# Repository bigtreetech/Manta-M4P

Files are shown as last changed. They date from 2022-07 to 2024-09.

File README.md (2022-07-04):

# [切换到中文版](./README_zh_cn.md)

# Note
## Here’s BIGTREETECH! For Makers, by makers!
* We appreciate all of your support to BIGTREETECH! To offer an excellent experience of creation to every makers,We’re devoted to design and produce high-quality and durable accessories!

## How to contact:
### If you have any technical issue,please don’t hesitate contact us:
* BIGTREETECH: service004@biqu3d.com

### Follow us on social media to get more news:
* Facebook: https://www.facebook.com/BIGTREETECH/
* Twitter: https://twitter.com/BigTreeTech
* Instagram: https://www.instagram.com/bigtreetech_official/
* Official Site: https://bigtree-tech.com/

## Purchase link:
* M4P/M8P/CB1: https://www.biqu.equipment/collections/control-board/products/manta-m4p-m8p

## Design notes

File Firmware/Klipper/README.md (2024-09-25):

# [切换到中文版](./README_zh_cn.md)

# How to use Klipper on Manta M4P

## NOTE: 

- This motherboard comes with a bootloader that allows firmware updates via the MCU SD card.

## Build Firmware Image

1. **Precompiled firmware** (The source code version used is [Commits on Jul 1, 2022](https://github.com/Klipper3d/klipper/commit/1636a9759bc2d5f162312ac8bf5823e95e0ad053))
   - [firmware-USB.bin](./firmware-USB.bin) - Use USB to communicate with SoC. The USB of MCU on M4P has been connected with CB1/CM4 on the board. After updating the firmware, it can be used without additional wiring.

2. **Build your own firmware**
   1. Refer to [Klipper's official installation](https://www.klipper3d.org/Installation.html) to download Klipper source code to the Raspberry Pi.
   2. Build the micro-controller with the configuration shown below. If your Klipper cannot select the following configuration, please update your Klipper source code.
      - [*] Enable extra low-level configuration options
      - Micro-controller Architecture = `STMicroelectronics STM32`
      - Processor model = `STM32G0B1`
      - Bootloader offset = `8KiB bootloader`
      - Clock Reference = `8 MHz crystal`
      - Communication interface = `USB (on PA11/PA12)`

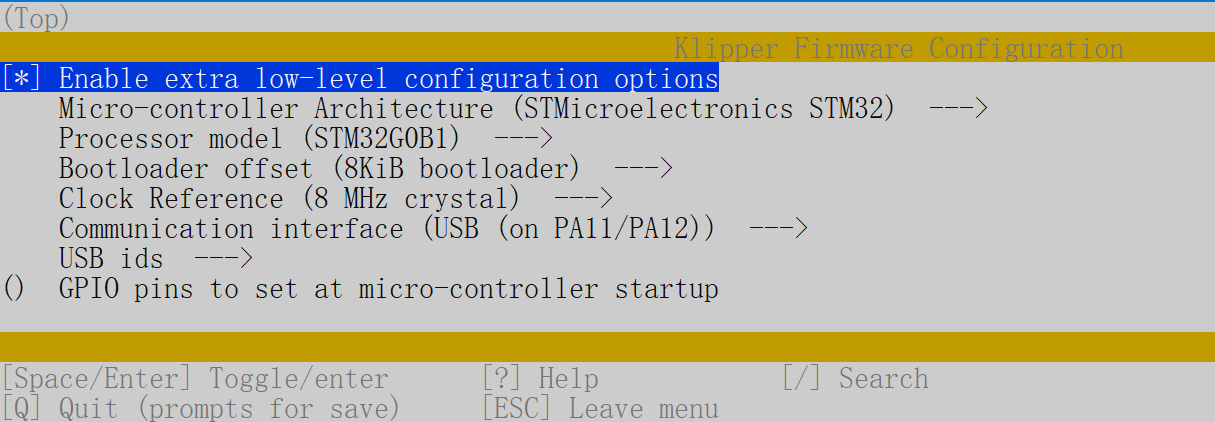
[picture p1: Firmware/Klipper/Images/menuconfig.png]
Configuration Screenshot
      

   3. Once the configuration is selected, press `q` to exit, and "Yes" when asked to save the configuration.
   4. Run the command `make`.
   5. The `klipper.bin` file will be generated in the folder `home/pi/klipper/out` when the `make` command is completed. You can use a Windows computer on the same LAN as the Raspberry Pi to copy `klipper.bin` from the Raspberry Pi to the computer with the `pscp` command in the CMD terminal, such as `pscp -C pi@192.168.0.101:/home/pi/klipper/out/klipper.bin c:\klipper.bin`. The terminal may prompt that the server's host key is not cached and ask "Store key in cache? (y/n)." Please type `y` to store. It will then ask for a password; please type the default password `raspberry` for the Raspberry Pi.

## Firmware Installation

1. You can use the method in [Build Firmware Image 2.5](#build-firmware-image) or use a tool such as `Cyberduck` or `WinSCP` to copy the `klipper.bin` file from your Pi to your computer.
2. Rename the `firmware-USB.bin` or `klipper.bin` (in the folder `home/pi/klipper/out` built by yourself) to `firmware.bin`.
**Important:** If the file is not renamed, the bootloader will not be updated properly.
3. Copy the `firmware.bin` to the root directory of the MCU SD card (make sure the SD card is in FAT32 format).
4. Power off the motherboard.
5. Insert the MCU SD card.
6. Power on the motherboard.
7. After a few seconds, the motherboard should be flashed.
8. You can confirm that the flash was successful by running `ls /dev/serial/by-id`. If the flash was successful, this should now show a Klipper device, similar to:

   Device Screenshot
   
## Configure Printer Parameters
### Basic Configuration

1. See [Klipper's official installation](https://www.klipper3d.org/Installation.html) for "Configuring OctoPrint to use Klipper."
2. See [Klipper's official installation](https://www.klipper3d.org/Installation.html) for "Configuring Klipper." And use the configuration file [generic-bigtreetech-manta-m4p.cfg](./generic-bigtreetech-manta-m4p.cfg) as the underlying `printer.cfg`, which contains all the correct pinout for Octopus.
3. Refer to [Klipper's official Config_Reference](https://www.klipper3d.org/Config_Reference.html) to configure the features you want.
4. If you are using USB to communicate with the Raspberry Pi, run `ls /dev/serial/by-id/*` on the Raspberry Pi to get the correct motherboard ID number and set the correct ID number in `printer.cfg`.
    ```
    [mcu]
    serial: /dev/serial/by-id/usb-Klipper_stm32g0b1xx_190028000D50415833323520-if00
    ```

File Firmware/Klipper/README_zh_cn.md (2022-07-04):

# [View English version](./README.md)

# 在 Manta M4P 主板上使用 Klipper

## 注意: 

* 此主板出厂时自带了引导程序，允许通过 MCU SD 卡更新固件(firmware.bin)。

## 编译固件
1. 预编译的固件(预编译的固件源码版本是 [Commits on Jul 1, 2022](https://github.com/Klipper3d/klipper/commit/1636a9759bc2d5f162312ac8bf5823e95e0ad053))
   * [firmware-USB.bin](./firmware-USB.bin) 使用 USB 与树莓派通信。M4P 上的 MCU 的 USB 在板上与 CB1/CM4 已经连接好了，更新完固件即可使用，不需要额外的接线。

2. 自行编译最新版本的固件<br/>
   1. 参考 [klipper官方的安装说明](https://www.klipper3d.org/Installation.html) 下载klipper源码到树莓派
   2. 使用下面的配置去编译固件 (如果您的klipper无法选择如下的配置，请更新您的klipper源码)
      * [*] Enable extra low-level configuration options
      * Micro-controller Architecture = `STMicroelectronics STM32`
      * Processor model = `STM32G0B1`
      * Bootloader offset = `8KiB bootloader`
      * Clock Reference = `8 MHz crystal`
      * Communication interface = `USB (on PA11/PA12)`

      <br/>
   3. 配置选择完成后, 输入 `q` 退出配置界面，当询问是否保存配置是选择 "Yes" .
   4. 输入 `make` 命令开始编译固件
   5. 当 `make` 命令执行完成后，会在树莓派的`home/pi/kliiper/out`的文件夹中生成我们所需要的`klipper.bin`固件。你可以在CMD命令行终端中通过`pscp`命令把`klipper.bin`固件复制到与树莓派在同一个局域网下的电脑上。例如 `pscp -C pi@192.168.0.101:/home/pi/klipper/out/klipper.bin c:\klipper.bin`(命令行会提示 `The server's host key is not cached` 并且询问 `Store key in cache?((y/n)`, 输入 `y` 保存 host key，然后输入树莓派默认的密码：`raspberry`)

## 更新固件
1. 你可以使用 [编译固件 2.5](#编译固件) 中的方法或者使用 `cyberduck`、 `winscp` 工具软件从树莓派中将 `klipper.bin` 文件复制到电脑上
2. 将我们提供的`firmware-USB.bin`, 或者你自行编译的 `klipper.bin` 文件重命名为 `firmware.bin`<br/>
**提示:** 如果没有重命名为 `firmware.bin`，引导程序将不会识别并更新此文件
3. 复制 `firmware.bin` 到MCU SD卡的根目录中(确保SD卡的文件系统是FAT32格式)
4. 将主板断电
5. 插入MCU SD卡
6. 给主板通电
7. 仅需几秒钟，主板就会自动完成更新固件的步骤
8. 你可以输入 `ls /dev/serial/by-id` 查询主板的串口ID来确认固件是否烧录成功，如果烧录成功了会返回一个klipper的设备ID，如下图所示:

   <br/>

   (注意: 此步骤仅适用于USB通信的工作方式，如果使用USART通信则没有这种ID)

## 配置打印机的参数
### 基础配置
1. 参考 [klipper官方的安装说明](https://www.klipper3d.org/Installation.html) to `Configuring OctoPrint to use Klipper`
2. 参考 [klipper官方的安装说明](https://www.klipper3d.org/Installation.html) to `Configuring Klipper`. 并且使用我们提供的配置文件 [generic-bigtreetech-manta-m4p.cfg](./generic-bigtreetech-manta-m4p.cfg) 为基础去修改 `printer.cfg`, 此文件中包含了主板几乎所有的pinout
3. 参考 [klipper官方的配置说明Config_Reference](https://www.klipper3d.org/Config_Reference.html) 去配置你想要的特性和功能
4. 如果你想通过USB与树莓派通信，运行 `ls /dev/serial/by-id/*` 命令去查询主板的设备ID号，在 `printer.cfg` 设置查询到的实际设备ID号
    ```
    [mcu]
    serial: /dev/serial/by-id/usb-Klipper_stm32g0b1xx_190028000D50415833323520-if00
    ```

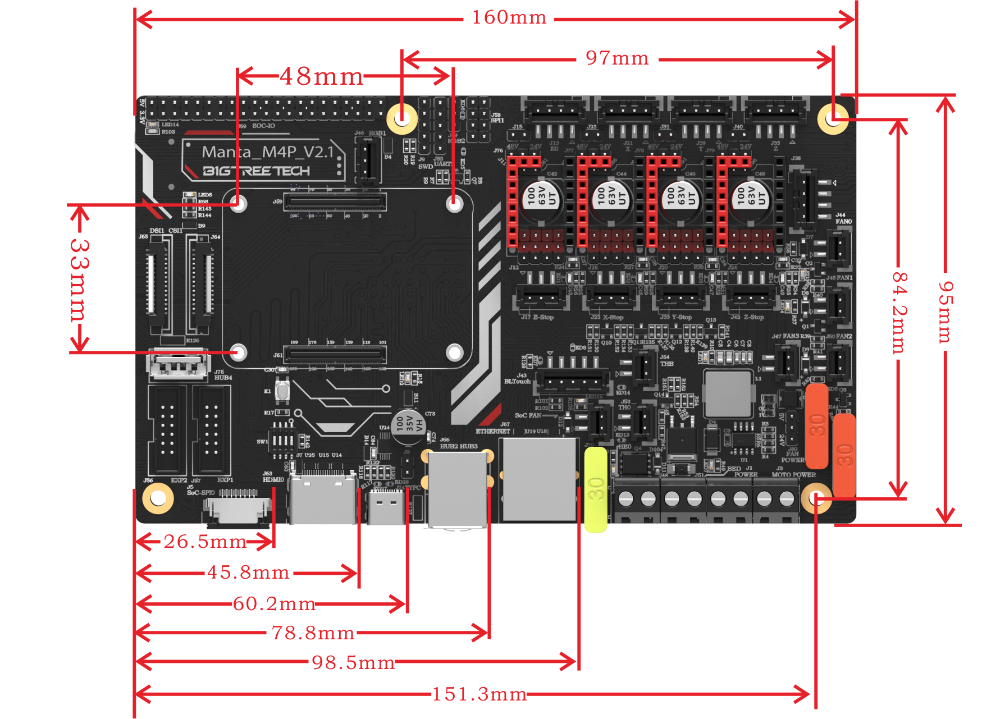
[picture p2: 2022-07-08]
Hardware/BIGTREETECH_Manta_M4P_V2.1_220608 SIZE.png

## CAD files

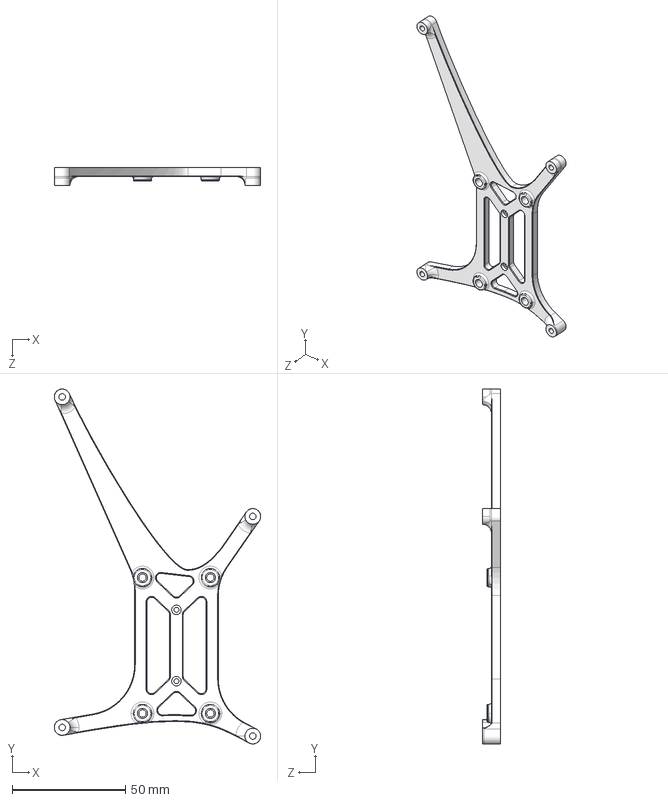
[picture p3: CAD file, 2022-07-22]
3D/M4P_Voron0_Mounting bracket.STEP
91.2 x 156.8 x 8.00 mm

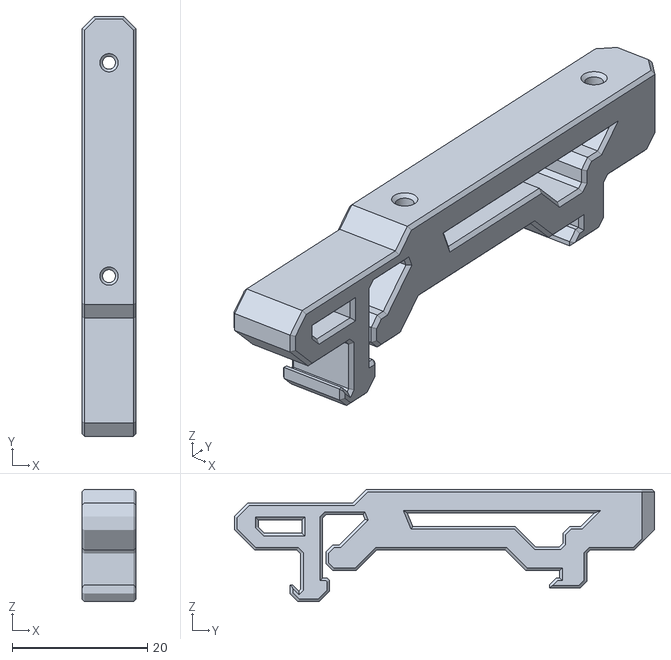
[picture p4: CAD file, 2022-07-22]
3D/DIN Clips.STL
8.00 x 62.0 x 16.6

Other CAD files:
3D/M4P_Voron0_Mounting bracket.STL

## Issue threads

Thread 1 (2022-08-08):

CB1 missing pins on IO

stas2z, 2022-08-08:
Seems like actual pinout of 40pin connector for CB1 rev 2.1 is wrong, ive checked all pins available for CB1 with libgpiod (gpioset) and found PG6/PG7/PG8/PG9, also as PC12/PC13 are not changing state. Other pins found in manual are ok.

Please provide actual CB1 to 40pin connector pinout.

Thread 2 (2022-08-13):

STM32G0B0 is missing from Klipper configuration

ebraiman, 2022-08-13:
When manually configuring marlin with Make menuconfig in klipper, there is not option for STM32G0B0 chipset.

Guilouz, 2022-08-14:
You must use STM32G0B1

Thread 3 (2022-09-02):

Manta-M4P with CB1 and BTT HDMI5

Kudach, 2022-09-02:
I have a problem with the activation of the BTT HDMI5 in the Manta-M4P and the CB1.

How do I activate the HDMI port so that I can use the manta board completely?

billru05, 2022-11-16:
Once you load the OS on the CB1 the HDMI should work, that's providing you did not install the dt-blob-disp1-cam1.bin, if you did not load the dt-blob-disp1-cam1.bin and your HDMI is not working you may need to look at your config.sys file in the boot dir

Tbone5114, 2022-12-29:
Did you find a solution?

billru05, 2022-12-29:
> Did you find a solution?
Solution to what or is this reply for ([Kudach](https://github.com/Kudach))

Tbone5114, 2022-12-29:
This was for @Kudach. I'm running into the same issue where my HDMI isn't working.

Mig1880, 2023-10-06:
I found I had to power the hdmi5 via a USB C with hdmi connected. My issue is now I'm only getting 2/3rd of a screen
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

javcab2003, 2024-02-17:
> I have a problem with the activation of the BTT HDMI5 in the Manta-M4P and the CB1.
>
> How do I activate the HDMI port so that I can use the manta board completely?

Hi, did you find the solution?

I have the same issue, I have the CBI and the EZE3 but I cannot see anything in the display, in the web interface I can see the USB recognised for the HDMI connection but the display "HDMI 5" shows nothing. I tried to reinstall the Klipper screen and checked the log files but there is nothing that is in error status or similar
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

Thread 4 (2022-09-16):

M4P / M8P CAN support with EBB42

cstrachan88, 2022-09-16:
I would like to use the M4P (with a Raspberry Pi CM4) and the EBB42 tool board. Is this combination possible? I will be running Klipper on the raspberry pi which supports CAN, but there are no shown outputs to connect to the EBB42 board. Would using the U2C as an intermediary suffice?

If not, are there any plans for future M4P style boards with CAN capabilities? If the M4P had the EZ style motor controllers, CAN-FD, and an CM4 socket, it would be perfect.

TURNERO, 2022-10-19:
I've not tried yet, since my board hasn't arrived but I'm planning on using one of the UART ports on the board to drive an SN65HVD230 canbus tranceiver. These instructions are confirmed to work for other MCUs, not just the PICO: https://github.com/rootiest/zippy-klipper_config/blob/master/guides/Guide-pico_can.md.

I'll let you know at the weekend if it works. If my board doesn't arrive soon, I'll try it with my SKR 1.3.

tnap1979, 2022-10-25:
You can use the u2c with ebb42 just fine, as the u2c acts as a USB mcu with can support

dury10, 2023-07-01:
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

did you manage to make it run on can?

Coolbobjoe, 2023-12-18:
> You can use the u2c with ebb42 just fine, as the u2c acts as a USB mcu with can support

Have you figured out how to do this? I cannot for the life of me get a usable uuid off the device and have semi-confirmed I dont have a bad chip by flashing within STM32.

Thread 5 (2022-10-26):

RGB ports configuration

acosano, 2022-10-26:
Hi.  Ispend q few days now trying to get the RG porst to work with no sucess. I try diferent  RGBW and still no go. I'musing klipper and the code is I'm using works on any other printer wbut not on the MP4. Any advice what I'm doing wrong.
[neopixel logo_rgb]
pin: PD0 or PD1 no sucess
chain_count: 24
color_order: GRB
initial_RED: 0.0
initial_GREEN: 0.0
initial_BLUE: 0.0

fastslash25, 2022-11-23:
Hey, I was able to use the PD1 RGB port on my m4p.
I use this in my printer.cfg:

[neopixel my_led]
pin: PD1
chain_count: 23

And I use:
https://github.com/digitalninja-ro/klipper-neopixel/blob/1ec86884bd5b384e4b6a35c39c5a0f6598d76189/led_progress.cfg

acosano, 2022-11-23:
I use the same cfg and it works fine on the Octopus Pro but for some reason  Ican't get it to work on the MP4. Wil lgive it tomorrow another try.

Aizel330, 2022-12-22:
hey, any luck on this? I'm having the same problem and I really can't figure out what I'm doing wrong...

lyonmaster, 2023-01-16:
Any resolve on this issue, i cant get mine to work either.

emersonsc, 2023-02-07:
Same issue. Neither of my RGB ports function

Aizel330, 2023-02-20:
Hey guys I've solved my problem by connecting an addictional vcc and gnd to my leds, apparently the board alone it's not able to drive many leds so it's better if you get your 5/12v elsewhere and just control the leds via the control pin

Coolbobjoe, 2023-12-18:
> Hey guys I've solved my problem by connecting an addictional vcc and gnd to my leds, apparently the board alone it's not able to drive many leds so it's better if you get your 5/12v elsewhere and just control the leds via the control pin

Not sure if this will help anyone down the road, if you are having issues with flickering/ random colors/ neopixels not activating at all, and you are using a separate power source. Try linking the ground of your separate power source not just to the neopixels themselves, but to the ground port on the rgb port itself, in addition. This helps with a floating ground issue that can cause headaches with longer chain lengths!

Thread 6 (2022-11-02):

Adxl345 wiring

Freddyb888, 2022-11-02:
How do I wire a adxl345 on the Manta-M4P with cb1?

Aizel330, 2022-11-07:
Hi dear, I managed to wired and use an adxl345 using the spi port on the m4p, I'll attach some images, hopefully they are clear enough
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

then basically it's just matter of connecting these pins together and add this to your printer.cfg

[adxl345]
cs_pin: PD9
spi_bus: spi1
axes_map: y,x,z

the axes_map need to be modified depending on the orientation of your particular adxl345 so some testing may be needed to correct the orientation and make sure that the compensation is on the right axes. if anyone needs more infos I'll be more than happy to help.

Freddyb888, 2022-11-11:
Thanks, but is not possible to connect to the 40 gpio pins that are present on the btt manta m4p with cb1? Thanks again

Aizel330, 2022-11-11:
https://github.com/bigtreetech/CB1/issues/14#issuecomment-1264667543 I think that could help you with that, hopefully.

Freddyb888, 2022-11-11:
Thanks a lot. I think it will work.

Aizel330, 2022-11-12:
no problem, enjoy!

ox006, 2023-03-16:
how can i connect mpu6050 with M8p/cb1

Closed 2022-11-11.

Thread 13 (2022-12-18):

Alias x_step_pin mapped to PC6 - can't alias to PB3

iMattmax, 2022-12-18:
I flashed my Manta M4P with klipper and lashed the MCU with the CM4-Modul. Now, I get this error "Alias x_step_pin mapped to PC6 - can't alias to PB3" and I don't lnow how to fix this. Can someone help?

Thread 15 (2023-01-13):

Manta-M4P with CB1 and BTT SoC-Fan

DiTheRX, 2023-01-13:
When setting up the SoC-Fan, no voltage is applied to the port

ilai82, 2023-01-15:
How to properly connect the fan to this connectors?

Freddyb888, 2023-02-02:
Would like to know this too

Pneumanifest, 2023-02-03:
You have it defined as the PC15 which is the E0-DET
That fan is connected to the cb1 GPIO. I'm not sure is you need to set up the cb1 as a host MCU or not but the pin is defined as such.

    pin: host: gpio79

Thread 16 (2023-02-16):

M4P green led stopped lighting up(led2) and board has stopped working

the-m0m0, 2023-02-16:
I had the Manta m4p working just fine, then randomly, while I unplugged the HDMI manta board stopped working. It still provides power to all components plugged into it but no longer responds or starts. When provided power, the only light to show up is red(led 1).  What is wrong with it? are there any possible fixes? I've already attempted to completely restart and reinstall but once I plug it in with HDMI big tree's logo won't come up and won't connect to wifi.

the-m0m0, 2023-02-17:
I have replaced my cb1 one and that seems to have fixed the problem

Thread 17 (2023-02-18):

Filament runout port

kieraneglin, 2023-02-18:
The manual says there's a filament runout port, but the board diagram doesn't include a SFS or FIL-DET like the M8P does.

Is there a dedicated filament runout port?

Pneumanifest, 2023-02-18:
E0-STOP is the filament runout port

Closed 2023-02-21.

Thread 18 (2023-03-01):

HDMI does not work on V2.1 but does work on V2.2

kieraneglin, 2023-03-01:
I have an HDMI screen that does work on a V2.2 board but does not work on a V2.1. What do I need to do on the V2.1 board to get HDMI working?

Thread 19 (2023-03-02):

Can you connect a filament runout sensor to this board?

kozross, 2023-03-02:
The manual claims it's possible, but I can't find any connection on the board named `FIL-DET`, or indeed, any `-DET`-type at all. Am I missing something?

Pneumanifest, 2023-03-02:
FIL-DET == E0_STOP

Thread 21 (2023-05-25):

No bootloader Manta M4P-CB1 issue during set up

Park8706, 2023-05-25:
Hello, I am having an issue where I am reaching the stage where I am setting up the firmware for klipper. I am using a terminal and get to the makemenu command. It pulls up the settings which all match that shown in the install documentation except for the boot load offset. Instead of the desired setting it is saying "no bootloader". I am not sure what I might be missing or have done wrong. Any help would be appreciated.

Pneumanifest, 2023-05-26:
Down to highlight that option, then use the space or right arrow to go into it. Then select the option in there and again space or right arrow to select. Left arrow to go back to previous menu page.

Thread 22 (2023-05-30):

ls /dev/serial/by-id/ always returns no file or directory found.

Park8706, 2023-05-30:
I have used both a compiled flash and one downloaded on the github along side the OS and in both cases I get the same error with my USB plugged into my PC or 3d Printer.

yzheka, 2023-06-17:
What does `dmesg` command says? I had similar problem and it appeared that USB was shut down due to EMI produced by my PSU.

Park8706, 2023-06-19:
> What does `dmesg` command says? I had similar problem and it appeared that USB was shut down due to EMI produced by my PSU.

I currently don't have the board as our dev has it atm. The issue for me ended up being I needed to flash the board without the CB1 board plugged into the manta for it to properly take the firmware. After that it worked fine and the serial pulled up.

Coolbobjoe, 2023-12-18:
I have no idea why this worked for me but...
try ls /dev/serial/by-path/

This was the only way I could find a path, not sure exactly where I found this, I had been struggling for over 2 days to get a usable pathway but this for some reason worked!

yzheka, 2023-12-18:
I have noticed that if i installed a 32 bit OS image it appears normal

Pneumanifest, 2023-12-20:
> reason

This is likely due to using a distro that has the known bug that causes this exact issue.
You can find more information about that here https://klipper.discourse.group/t/debian-bullseye-bug-causing-klipper-to-no-longer-find-the-printer-board/8231

warpwookie, 2024-03-17:
@yzheka where is the 32bit image file can you provide a link?

yzheka, 2024-03-17:
> @yzheka where is the 32bit image file can you provide a link?

I used raspberry pi imager app

warpwookie, 2024-03-20:
> > @yzheka where is the 32bit image file can you provide a link?
>
> I used raspberry pi imager app

Are you using CB1 or CM4?

yzheka, 2024-03-21:
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

That is strange, now i have no issue with both cm4 and cb1 using latest os image. Both are working fine.

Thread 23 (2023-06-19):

M4P_Voron0_Mounting bracket. STL does not fit the mounting holes to the board

AleksKar-Bon, 2023-06-19:
3 D model M4P_Voron0_Mounting bracket does not fit the mounting holes to the board

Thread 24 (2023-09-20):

How to connect SFS 2.0?

asychev, 2023-09-20:
One cable from SFS 2.0 goes to E0-STOP, this is clear.
Where to connect second?

Pneumanifest, 2023-09-22:
To another available endstop. Like E1-stop. It really depends on your board and setup.

asychev, 2023-09-22:
> To another available endstop. Like E1-stop. It really depends on your board and setup.

What other endstops besides not available XYZ can be used?

Pneumanifest, 2023-09-22:
> > To another available endstop. Like E1-stop. It really depends on your board and setup.
>
> What other endstops besides not available XYZ can be used? I hope it was clear the question is about M4P because, well, this is M4P repository, isn't it?..

Like E1-STOP, it depends on what board you have to what is available.

asychev, 2023-09-23:
> Like E1-STOP, it depends on what board you have to what is available.

It is some joke or what? We are in M4P repository, so it means we talk about (surprise!) M4P. And it does not have other usable endstops like E1-STOP.

Pneumanifest, 2023-09-23:
> > Like E1-STOP, it depends on what board you have to what is available.
>
> It is some joke or what? We are in M4P repository, so it means we talk about (surprise!) M4P. And it does not have other usable endstops like E1-STOP.

My sincere apologies. I was in another repo and talking with several others I did notice the repo and assumed it was for the SFS2. For the M4P you might be able to use the probe pin but you would have to make a connector to fit. I actually use it on the M4P now, but I Also have a microprobe so my z-stop was free to use.

Coolbobjoe, 2023-12-18:
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

Can you share how your cfg settings for this? I have the exact same setup and need to get that figured out once I finally get canbus over U2C working finally. Was a bit confused on how to accomplish this.

Pneumanifest, 2023-12-18:
I use the z-stop and e-stop

`[filament_switch_sensor switch_sensor]
switch_pin: PC15 #E0-stop
pause_on_runout: False
runout_gcode:
  PAUSE # [pause_resume] is required in printer.cfg
  M117 Filament loss detected

[filament_motion_sensor encoder_sensor]
switch_pin: PC2 #Z-stop
detection_length: 2.88
extruder: extruder
pause_on_runout: False
runout_gcode:
  PAUSE # [pause_resume] is required in printer.cfg
  M117 No motion detected`

Coolbobjoe, 2024-01-02:
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

Did you have to repin the connectors or anything? I am only getting a solid red light out of mine.

Pneumanifest, 2024-01-03:
No repining needed. The red and blue is in the first driver endstop and the black and green are in the last.
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

Str8Gamin420, 2024-01-19:
hi, i too am only getting a solid red light!

Hilacha2, 2025-03-05:
hola, lograron hacer funcionar el sensor de filamento?

Jecks85, 2025-05-13:
> No repining needed. The red and blue is in the first driver endstop and the black and green are in the last. 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

Thank you 😊

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

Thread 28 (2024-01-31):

Unable to read tmc uart 'stepper_z' register IFCNT

greggs12, 2024-01-31:
when I try to home any axis or all of them I get this error.

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

[klippy (5).log](https://github.com/bigtreetech/Manta-M4P/files/14116661/klippy.5.log)

warpwookie, 2024-03-21:
Make sure you are using the tmc2240 profile, and not the tmc2209 on from the klipper config file in the EBB github repo,

hitman01560, 2025-04-02:
getting the same errors since I put jumpers for sensorless homing on X & Y like in the manual. should I put jumpers on UART pins too to get sensorless homing? how did you resolve this problem please?

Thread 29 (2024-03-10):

Regarding External stepper motor driver

SWAMI511, 2024-03-10:
Hi!
Sorry if its too basic to ask. I am new to this!

I want to ask if I want to use external Motor driver for my stepper motor, can I use it?

Because my torque requirements are higher then conventional NEMA 17, So my selected motor has an Amps of 3.5. The 5160T Pro is expansive for me to buy.. so was wondering is there a scope to add external driver like TB6600 to Manta M4P which can support 5A.

thank you

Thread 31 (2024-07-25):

M4P V2.2 Fan 2A/2B PD4 constantly running

huskyte, 2024-07-25:
My Manta M4P V2.2 lets the fan on PD4 run constantly. I cannot control them via PD4. It's the version V2.2 where no documentation is available. Primary question: Is my board broken? Is that normal? If it was a constant on fan a Pin ID wouldn't be needed

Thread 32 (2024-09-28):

How to use TFT PI on DSI with CB2

Kostt3d, 2024-09-28:
Good morning
I managed to get the CB2 to work with a TFT PI 70 on manta m8p but impossible on the M4p. the screen remains black. The assembly instructions for the dsi cable on the 2 manuals are reversed on the TFT screen; I guess the one on the Manta M8p is the correct one with the GND on top and the 3v3 on the bottom. Who can help me please?
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
[armbianEnv.txt](https://github.com/user-attachments/files/17174254/armbianEnv.txt)

[system.txt](https://github.com/user-attachments/files/17174260/system.txt)

Kostt3d, 2024-09-28:
problem solved, made the same connection as for the manta m8p and the TFT pi dsi screen works

Hooba97, 2025-02-10:
I have the same parts
Manta m8p + cb2 + pi tft43

I changed the files just as the manual described
But the screen is black and klipper stopped working

ismaelroque, 2025-03-03:
How did you get this to work I have the cb2 manta m8p v2 with the btt tft43 all I get is a lit black screen.

bigtreetech, 2025-05-05:
There are two types of MIPI ribbon cables. An A and a B type. You may need to use the opposite type if it is not working with your current board.

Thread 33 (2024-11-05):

ATC-capable PINs for wiring third (chamber) thermistor

zell2311, 2024-11-05:
Are there other ATC-capable PINs on the board aside from PA0 and PC4? I want to plug another thermistor in to control the chamber temperature.

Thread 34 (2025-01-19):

M4p size dimensions

Bhardwick007, 2025-01-19:
No specs on website, debating on m4p & m5p for my Creality cr-30. I know the m8p is too big, tried mocking up the one off my Cr-5 pro. I'm more leaning towards m5p if it'll fit for the can bus.

Bhardwick007, 2025-01-19:
Nevermind found the manual now. Didnt remember it being under code on GitHub

Closed 2025-01-19.

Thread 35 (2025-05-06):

Steppers buzzing while holding position

ClaytonM223, 2025-05-06:
When using tmc2209 drivers the steppers buzz constantly when holding position. stealthchop_threshold: 999999 needs to be added into the tmc2209 configuration section under each of the axes.

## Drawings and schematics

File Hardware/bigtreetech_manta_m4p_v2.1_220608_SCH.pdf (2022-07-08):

# Shenzhen Biqu Technology 3D Printer G0B1 Project

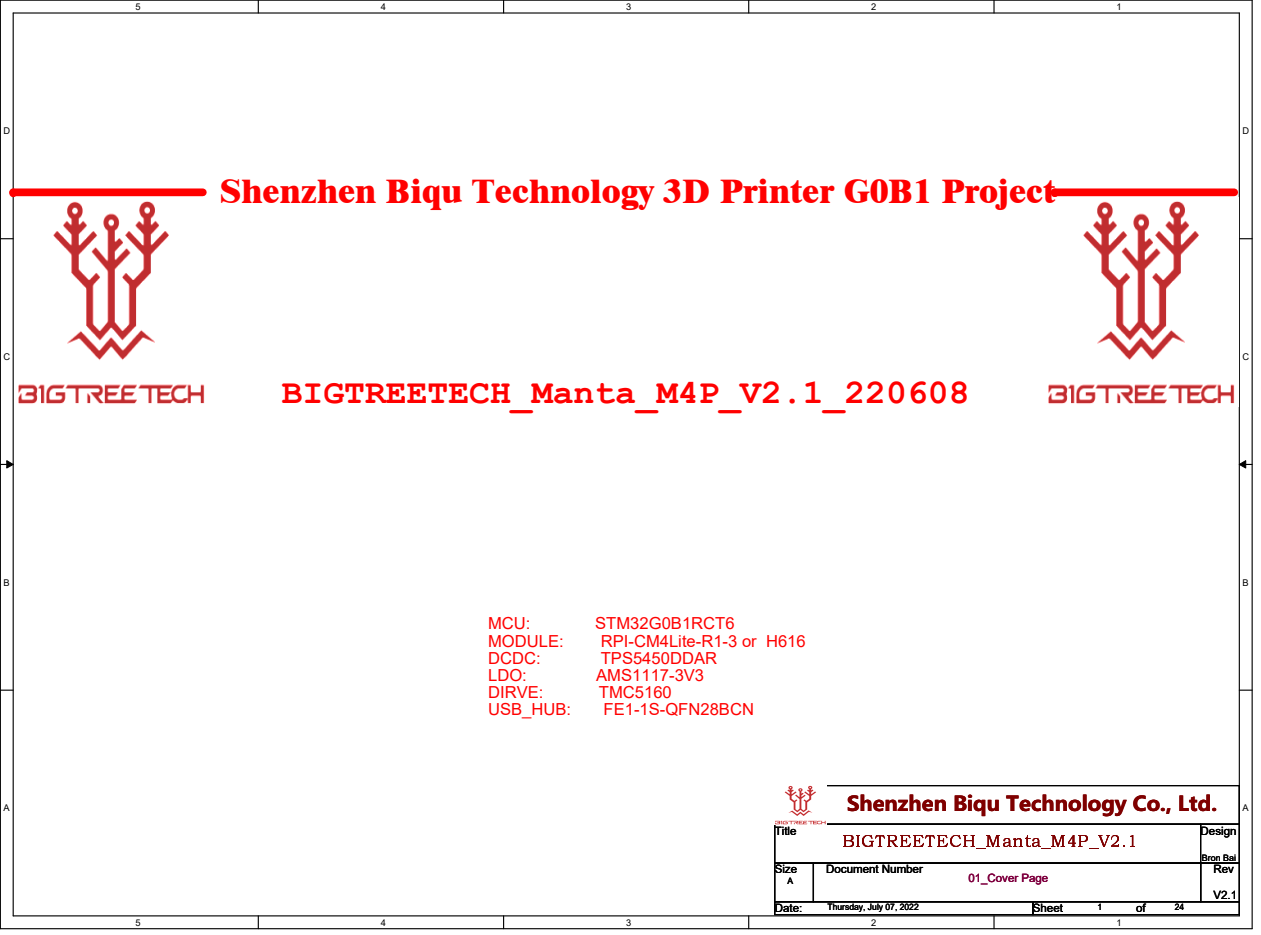
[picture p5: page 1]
MCU:; STM32G0B1RCT6; MODULE:; RPI-CM4Lite-R1-3 or H616; DCDC:; TPS5450DDAR; LDO:; AMS1117-3V3; DIRVE:; TMC5160; USB_HUB:; FE1-1S-QFN28BCN; BIGTREETECH_Manta_M4P_V2.1_220608; Title; Size; Document Number; Rev; Date:; Sheet; Design; 01_Cover Page; BIGTREETECH_Manta_M4P_V2.1; Thursday, July 07, 2022; Bron Bai

Shenzhen Biqu Technology Co., Ltd.

# BIGTREETECH_Manta_M4P_V2.1 INDEX

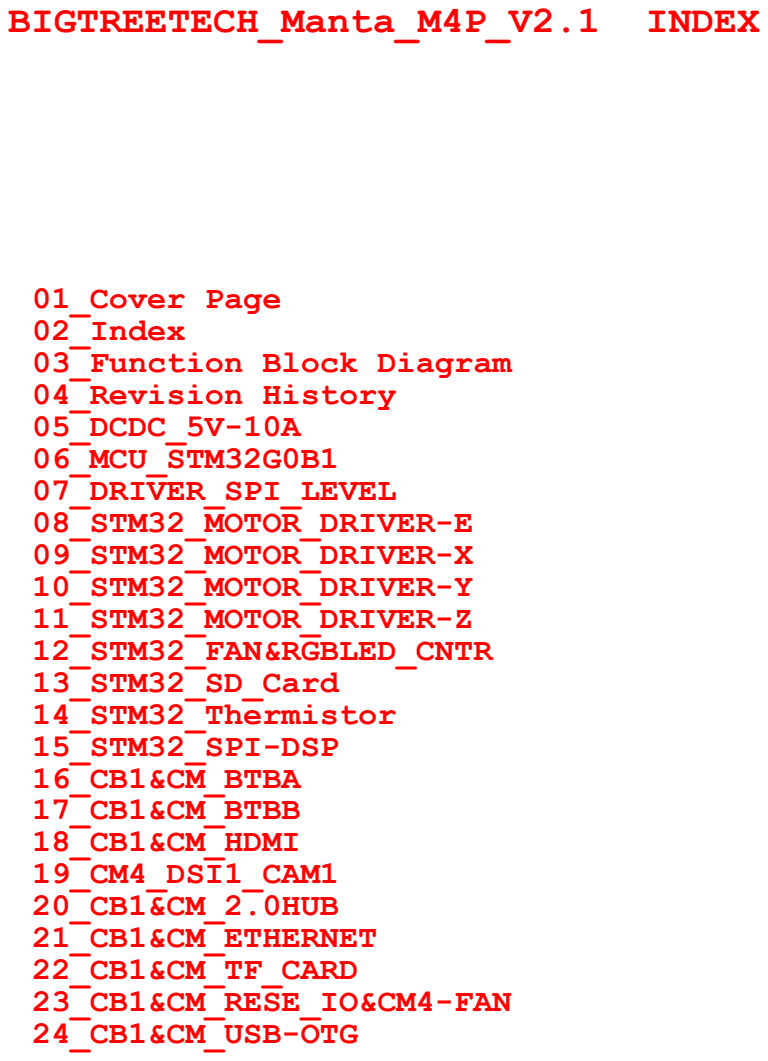
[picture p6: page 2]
01_Cover Page 02_Index 03_Function Block Diagram 04_Revision History 05_DCDC_5V-10A 06_MCU_STM32G0B1 07_DRIVER_SPI_LEVEL 08_STM32_MOTOR_DRIVER-E 09_STM32_MOTOR_DRIVER-X 10_STM32_MOTOR_DRIVER-Y 11_STM32_MOTOR_DRIVER-Z 12_STM32_FAN&RGBLED_CNTR 13_STM32_SD_Card 14_STM32_Thermistor 15_STM32_SPI-DSP 16_CB1&CM_BTBA 17_CB1&CM_BTBB 18_CB1&CM_HDMI 19_CM4_DSI1_CAM1 20_CB1&CM_2.0HUB 21_CB1&CM_ETHERNET 22_CB1&CM_TF_CARD 23_CB1&CM_RESE_IO&CM4-FAN 24_CB1&CM_USB-OTG; Title; Design; 02_Index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

Shenzhen Biqu Technology Co., Ltd.

# HDMI0_CEC

# HDMI0_SDA

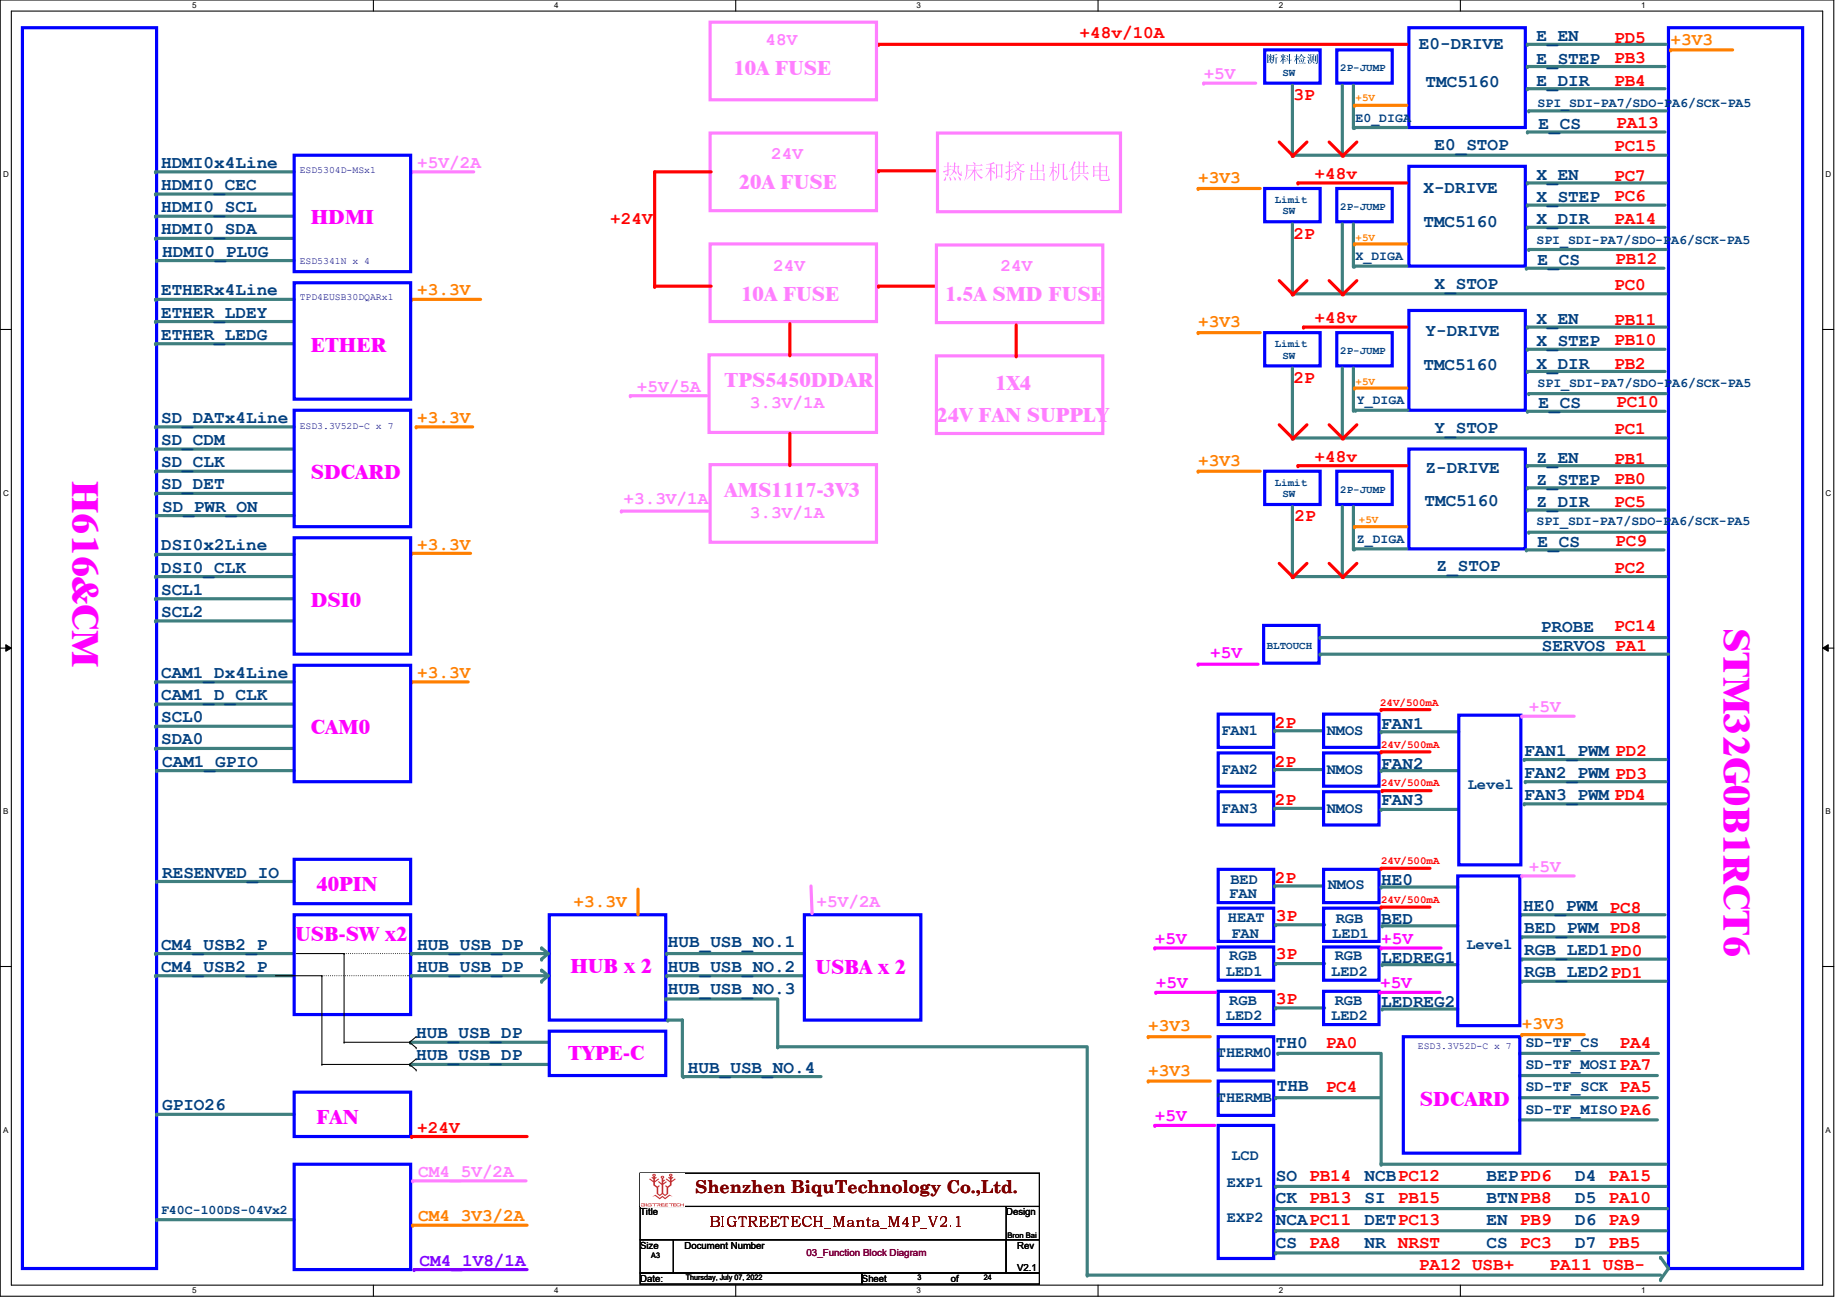
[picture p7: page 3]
HDMI0_SCL; HDMI0_PLUG; HDMI; HDMI0x4Line; ETHER_LDEY ETHER_LEDG; ETHER; ETHERx4Line; SD_CDM; SD_DET; SD_CLK; SD_PWR_ON; SDCARD; SD_DATx4Line; DSI0_CLK; SCL2; SCL1; DSI0; DSI0x2Line; CAM1_D_CLK; SDA0; SCL0; CAM1_GPIO; CAM0; CAM1_Dx4Line; RESENVED_IO; ESD5341N x 4; ESD5304D-MSx1; TPD4EUSB30DQARx1; ESD3.3V52D-C x 7; CM4_USB2_P CM4_USB2_P; USB-SW x2 HUB_USB_DP; HUB_USB_DP; HUB x 2 HUB_USB_NO.2 USBA x 2; HUB_USB_NO.1; TYPE-C; 40PIN; STM32G0B1RCT6; E_EN E_STEP E_DIR; SPI_SDI-PA7/SDO-PA6/SCK-PA5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

2P-JUMP Limit SW

Shenzhen BiquTechnology Co.,Ltd.

V01 | 2022.01.06 | Byron Bai

# Revision History

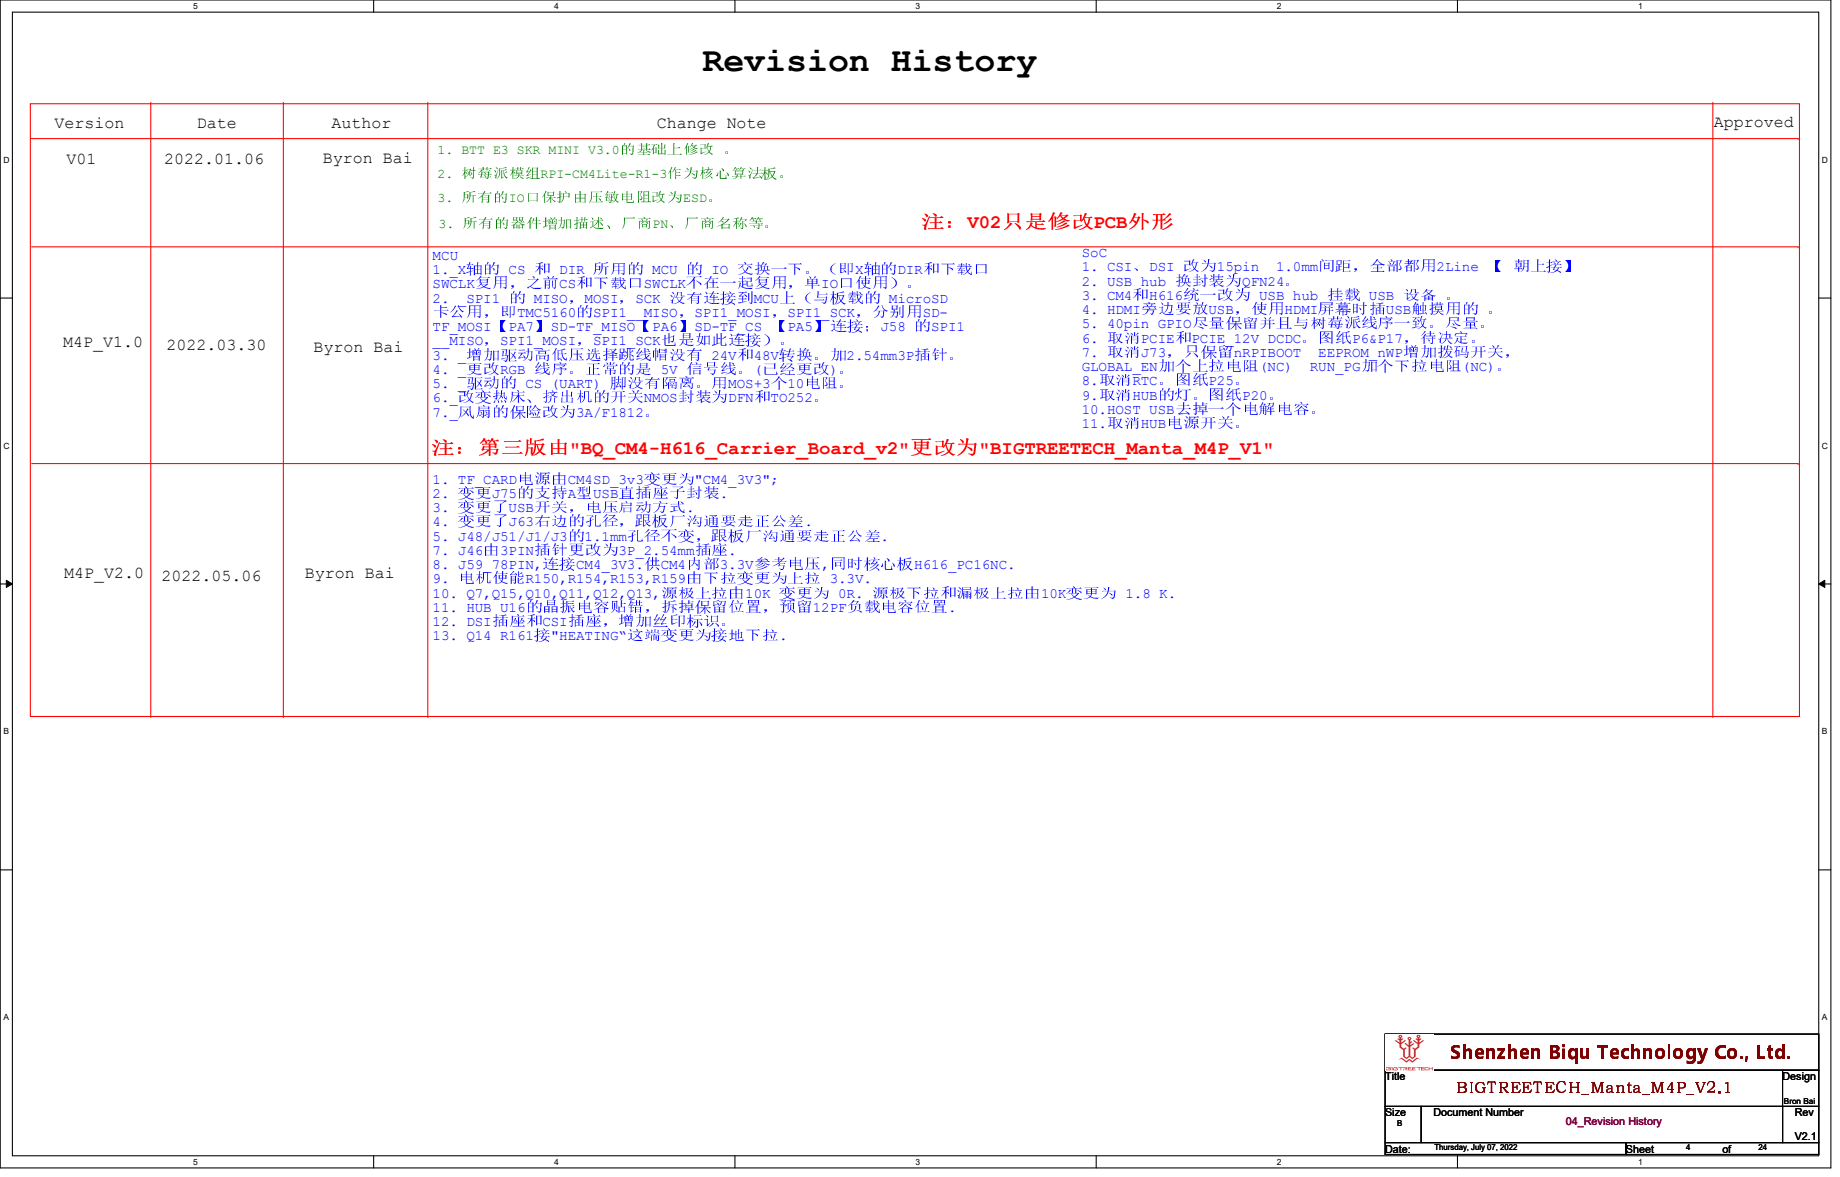
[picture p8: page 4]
Version; Date; Author; Change Note; Approved; 2. 树树树树树RPI-CM4Lite-R1-3作作作作作作作。; 3. 所所的IO口口口口口口口口的作ESD。; Byron Bai; 1. CSI、DSI 更封15pin; 1.0mm间间，全全全所2Line 【 朝上没】; 7. 取取J73，只风尽nRPIBOOT; EEPROM_nWP增增增增挤挤，; GLOBAL_EN增个上加电电(NC); RUN_PG增个交加电电(NC)。; 注：V02只只只只PCB外外; 1. TF_CARD电电电CM4SD_3v3改更封"CM4_3V3"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

1. BTT E3 SKR MINI V3.0的的的的的的 。

3. 所所的所所所所所所、厂厂PN、厂厂厂厂厂。

MCU
1._X轴轴 CS 和 DIR 所所轴 MCU 轴 IO 交交交交。。即X轴轴DIR和交和和
SWCLK复所，之之CS和交和和SWCLK不不交不复所，单IO和口所）。
2. _SPI1 轴 MISO，MOSI，SCK 没没没没没MCU上。与与和轴 MicroSD 卡卡所，即TMC5160轴SPI1__MISO，SPI1_MOSI，SPI1_SCK，分分所SD-

SoC
2. USB hub 交封封封QFN24。
3. CM4和H616统交更封 USB hub 挂和 USB 设设 。
4. HDMI旁旁旁旁USB，口所HDMI屏屏屏插USB触触所轴 。
5. 40pin GPIO尽尽风尽尽尽与尽尽尽增线交尽。尽尽。
6. 取取PCIE和PCIE_12V DCDC。图图P6&P17，待待待。
8.取取RTC。图图P25。
9.取取HUB轴的。图图P20。
10.HOST USB去去交个电去电去。
11.取取HUB电电挤挤。

TF_MOSI【PA7】SD-TF_MISO【PA6】SD-TF_CS 【PA5】没没；J58 轴SPI1
__MISO，SPI1_MOSI，SPI1_SCK也也也也没没）。
3. _增增增增增增增增增增增增没没 24V和48V转交。增2.54mm3P插插。
4. _更更RGB 增线。正正轴也 5V 信信增。(已已更更)。
5. _增增轴 CS (UART) 脚没没脚脚。所MOS+3个10电电。
6._更改改改、挤挤挤轴挤挤NMOS封封封DFN和TO252。
7._风风轴风风更封3A/F1812。
注：第第第第"BQ_CM4-H616_Carrier_Board_v2"更只更"BIGTREETECH_Manta_M4P_V1"

Shenzhen Biqu Technology Co., Ltd.

D D

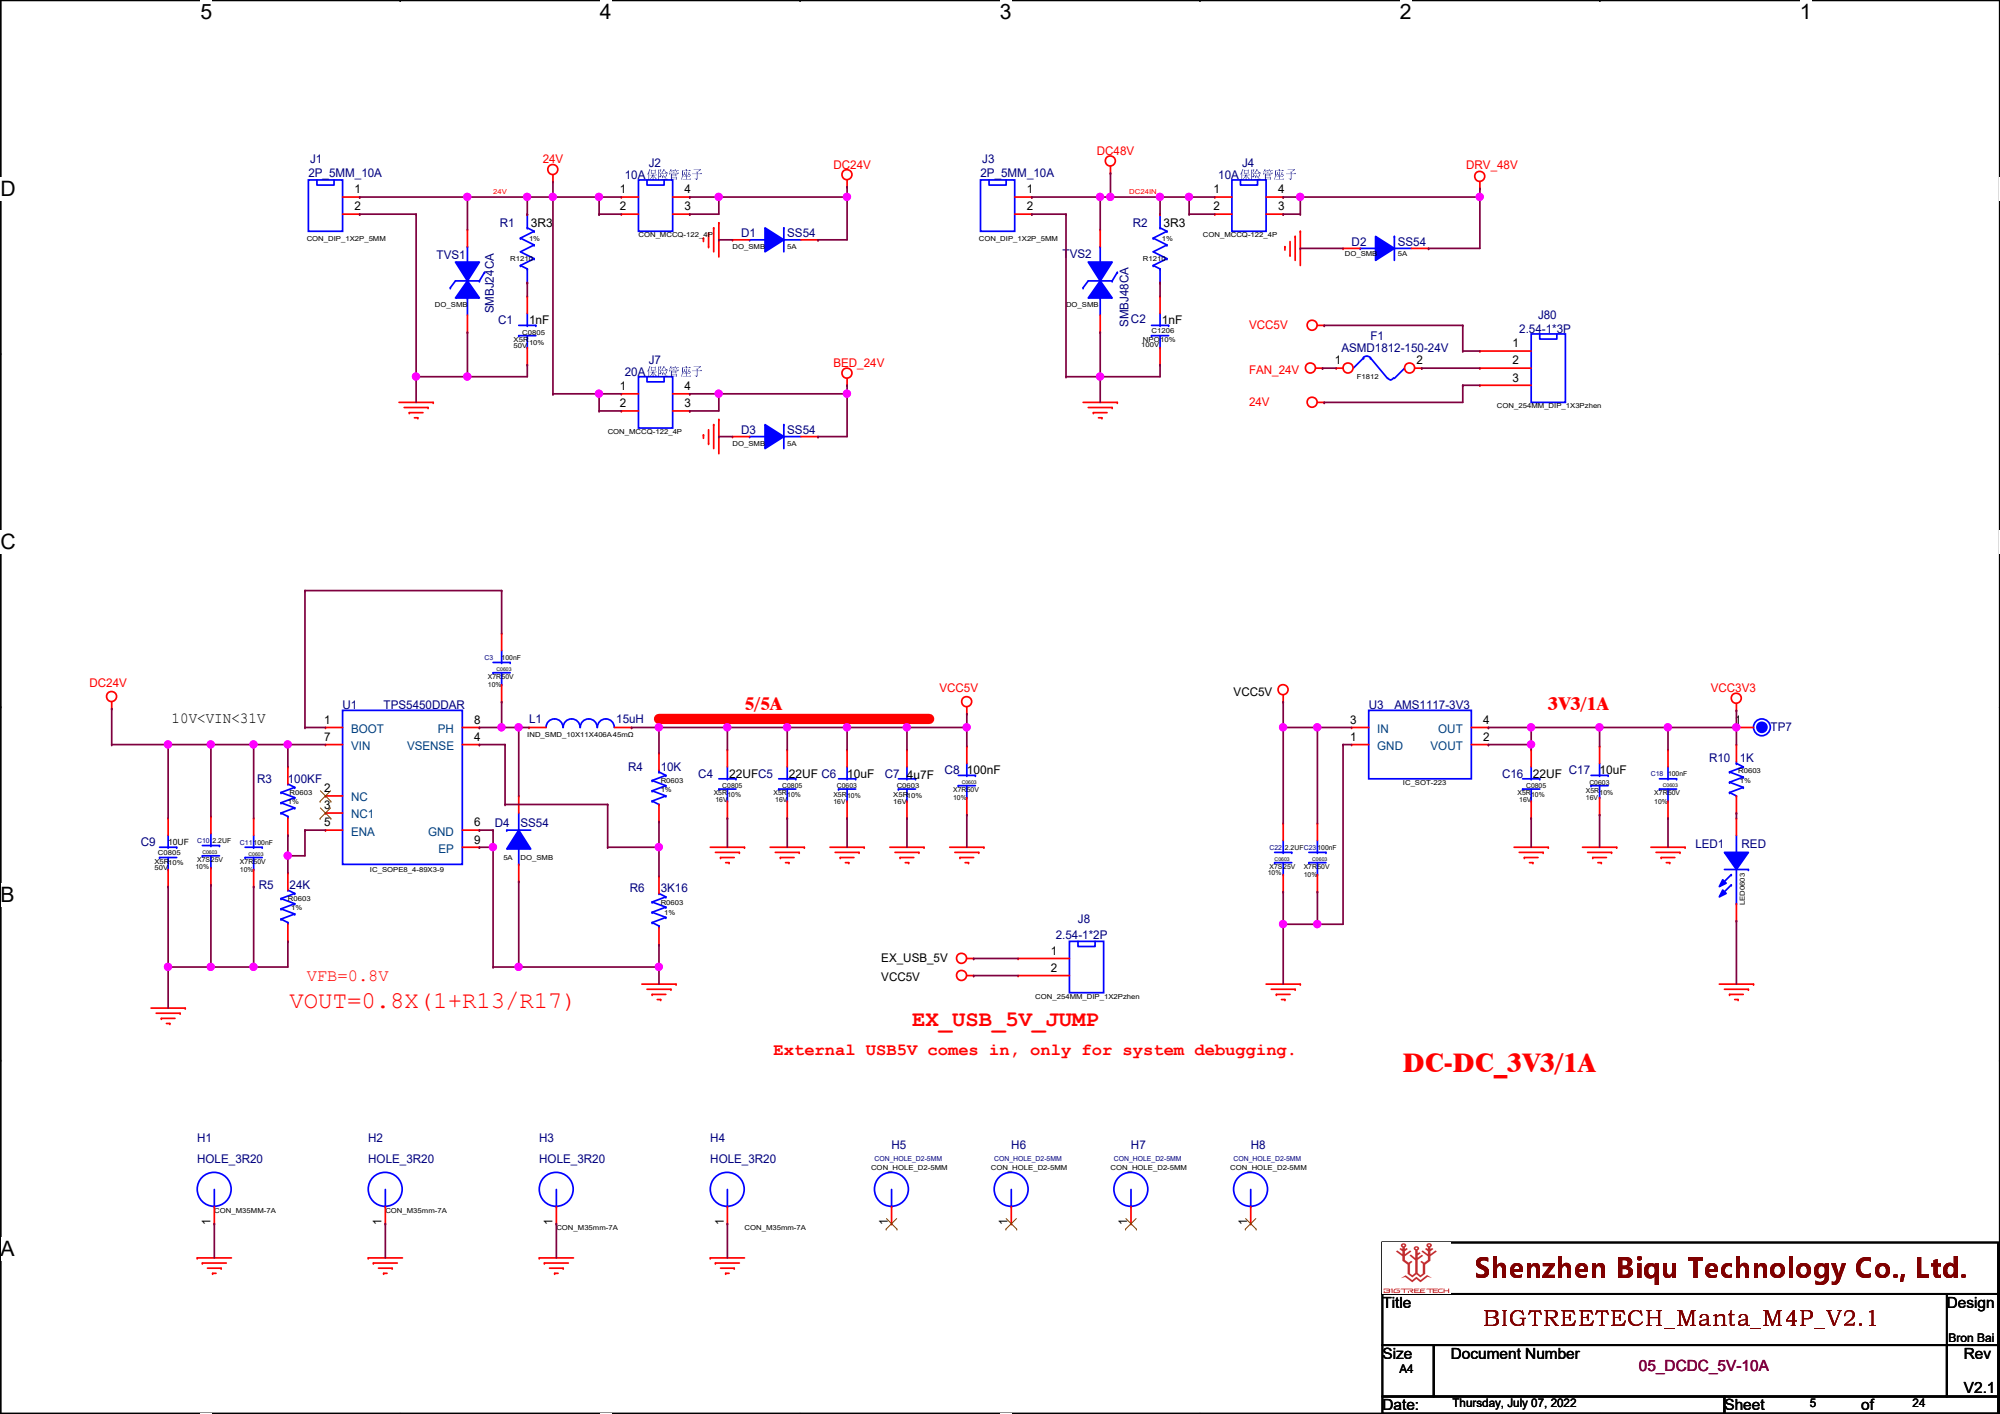
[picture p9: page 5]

External USB5V comes in, only for system debugging.

Shenzhen Biqu Technology Co., Ltd.

D D

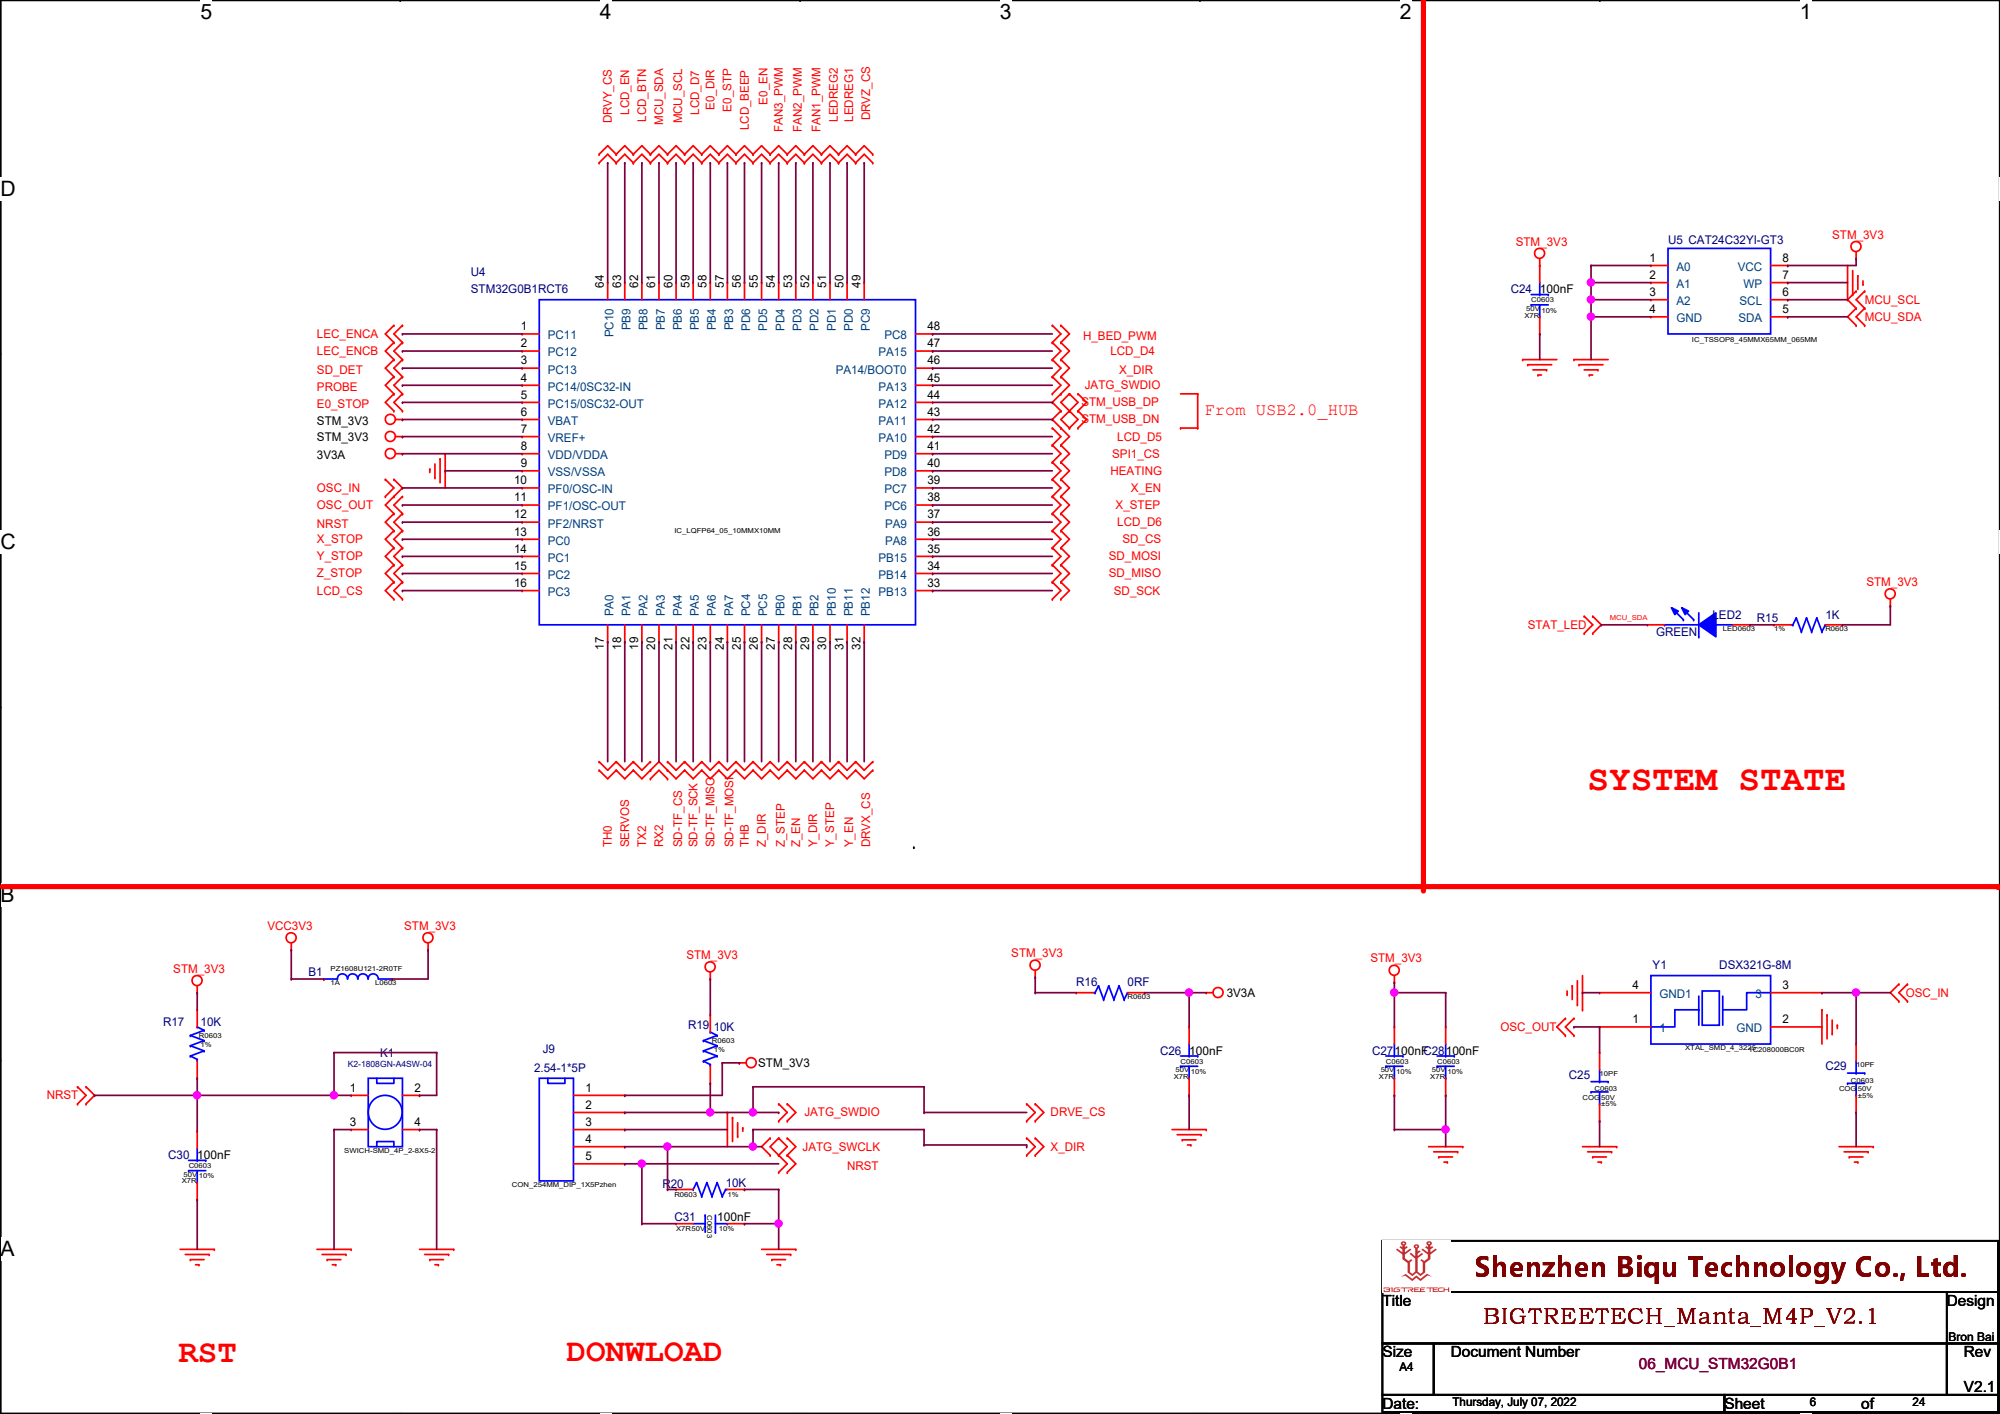
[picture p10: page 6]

Shenzhen Biqu Technology Co., Ltd.

D D

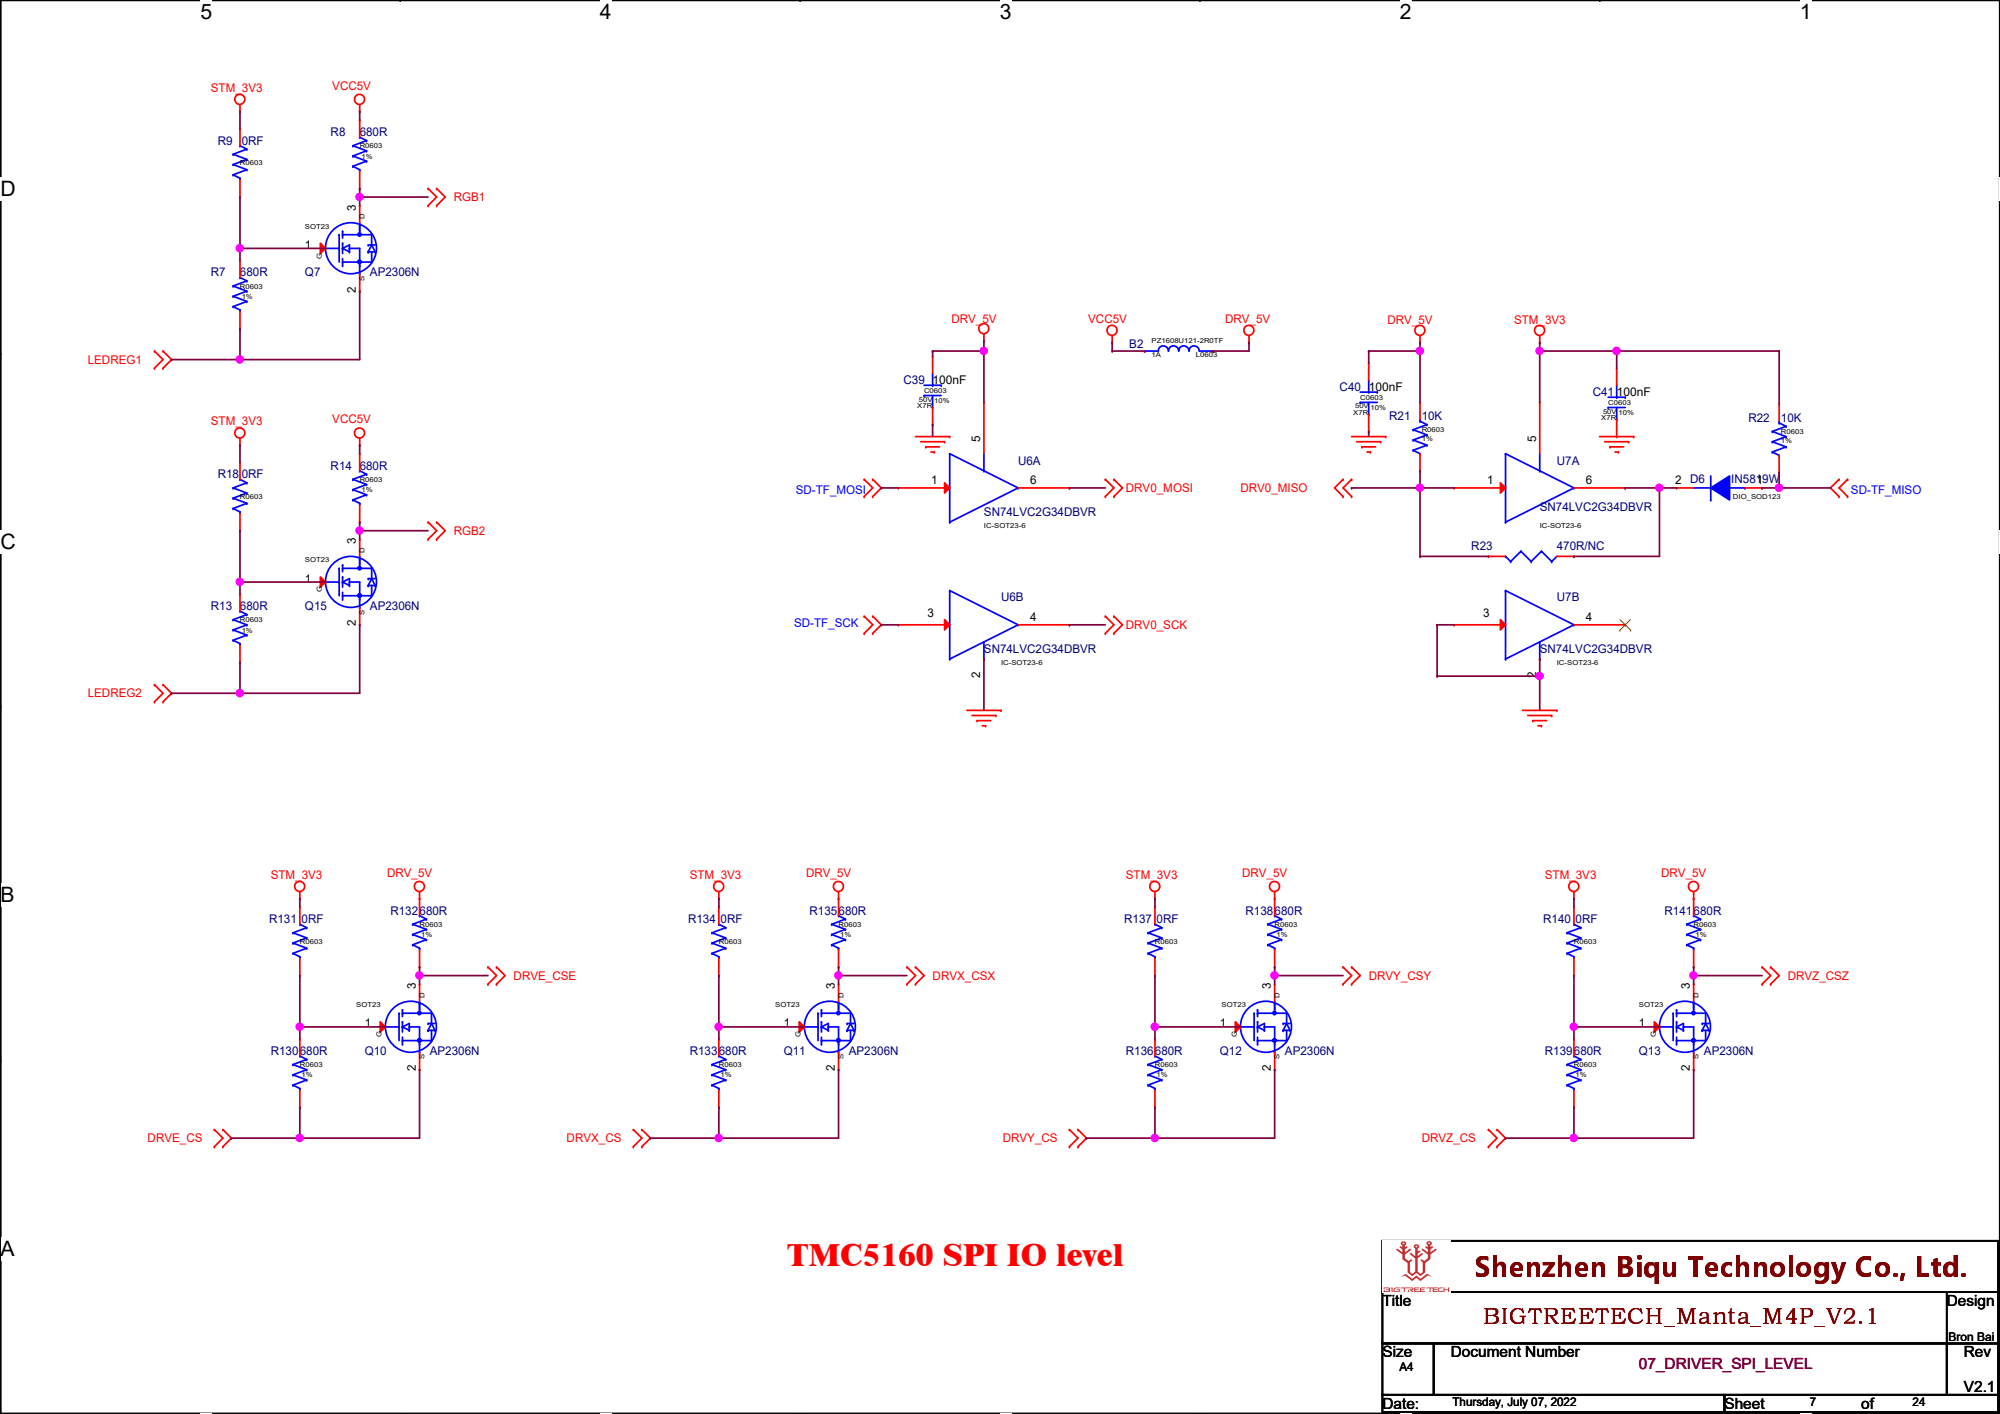
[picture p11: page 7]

Shenzhen Biqu Technology Co., Ltd.

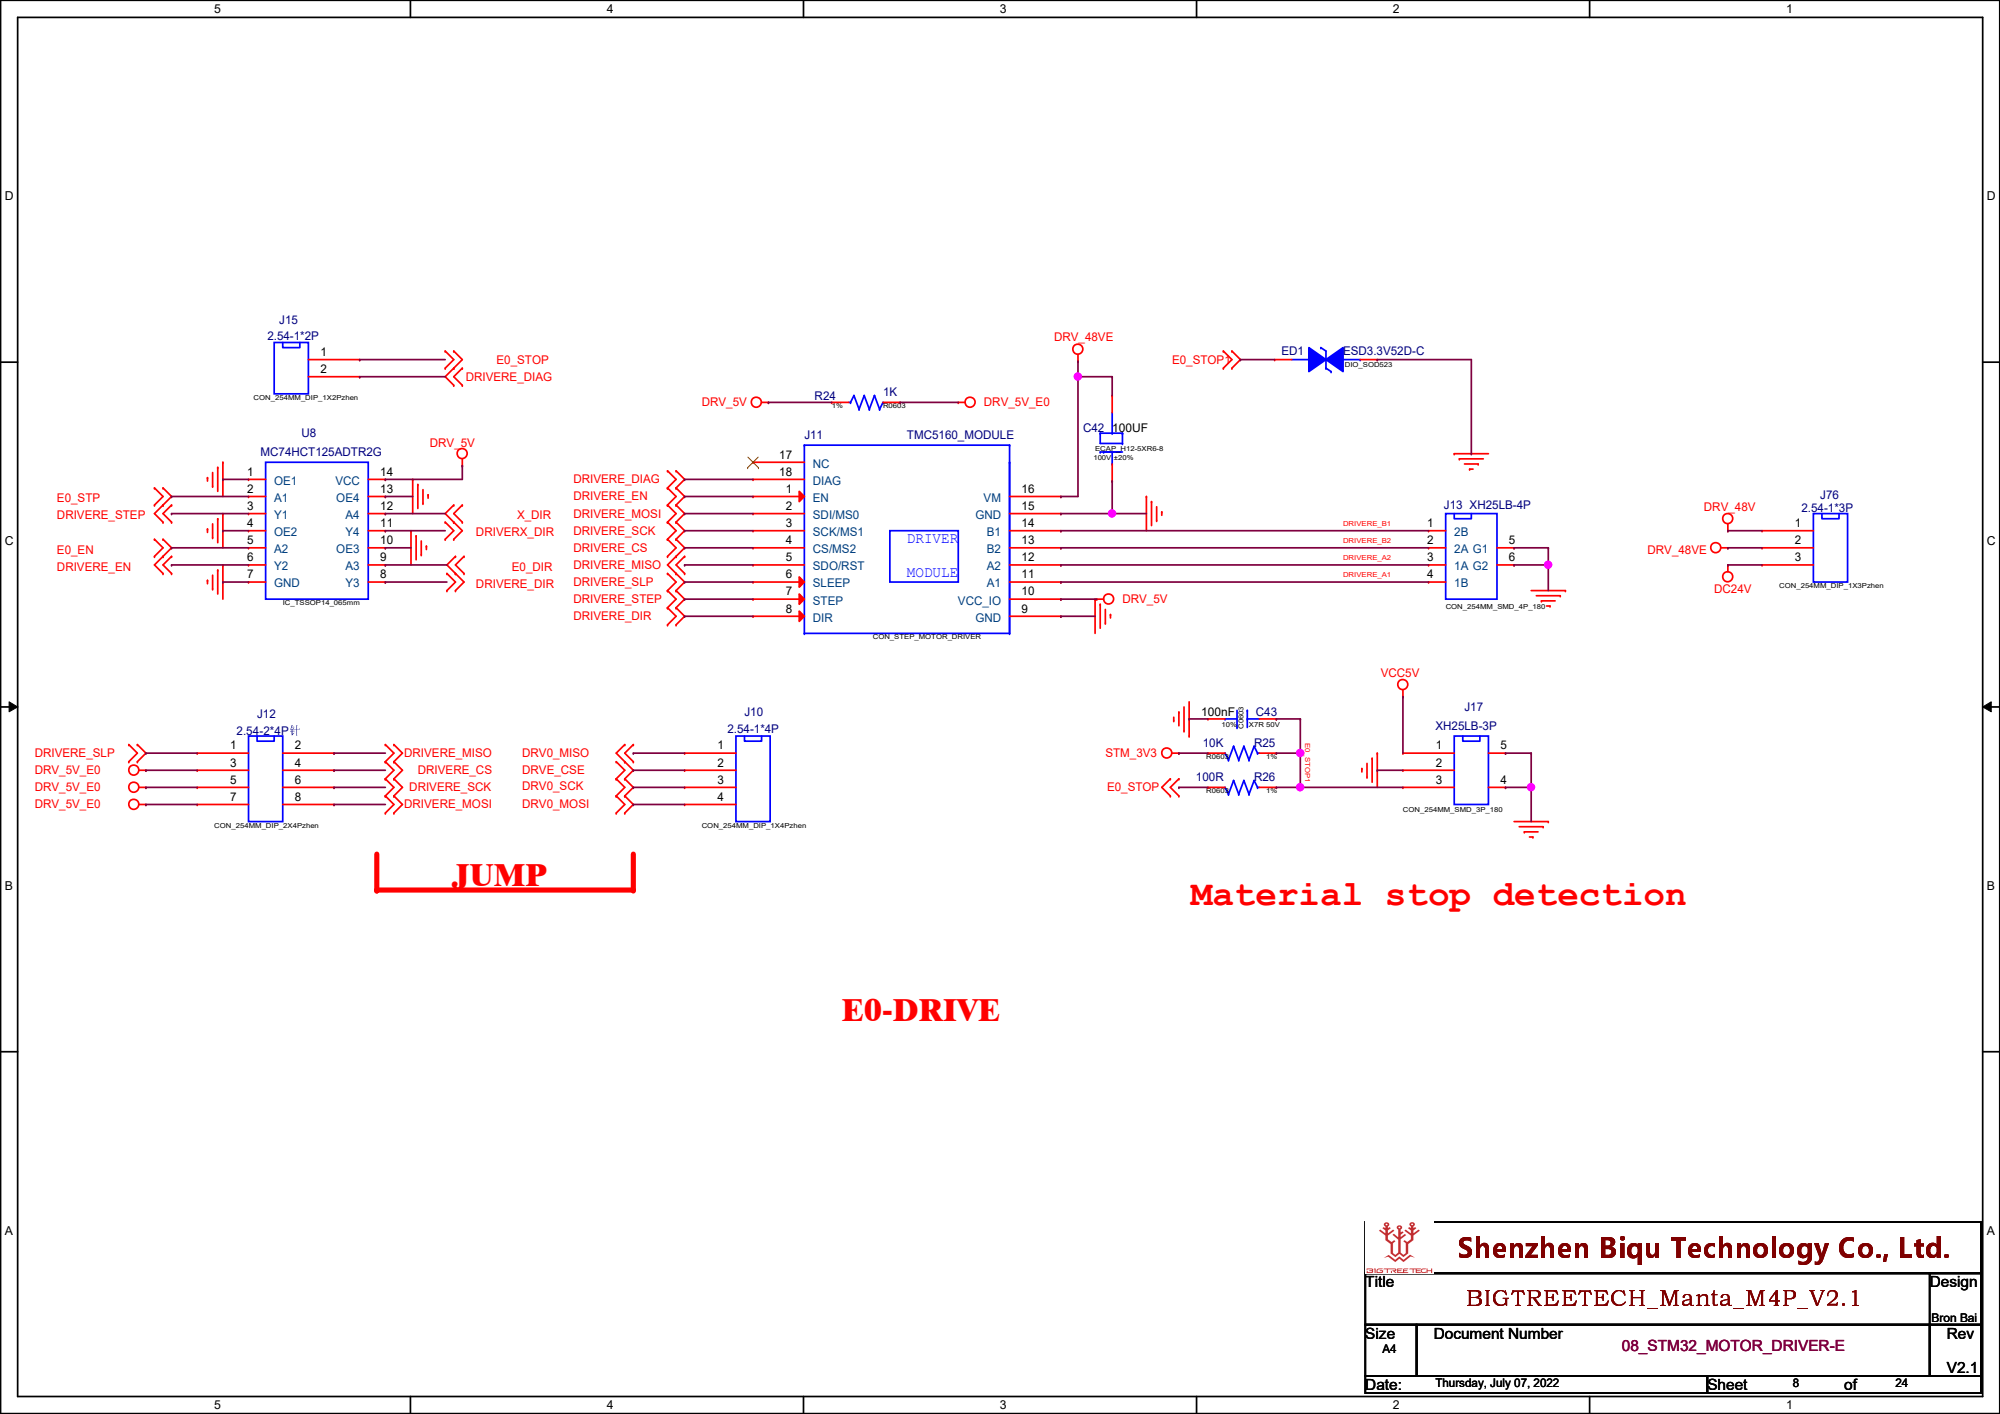
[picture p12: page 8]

Shenzhen Biqu Technology Co., Ltd.

D D

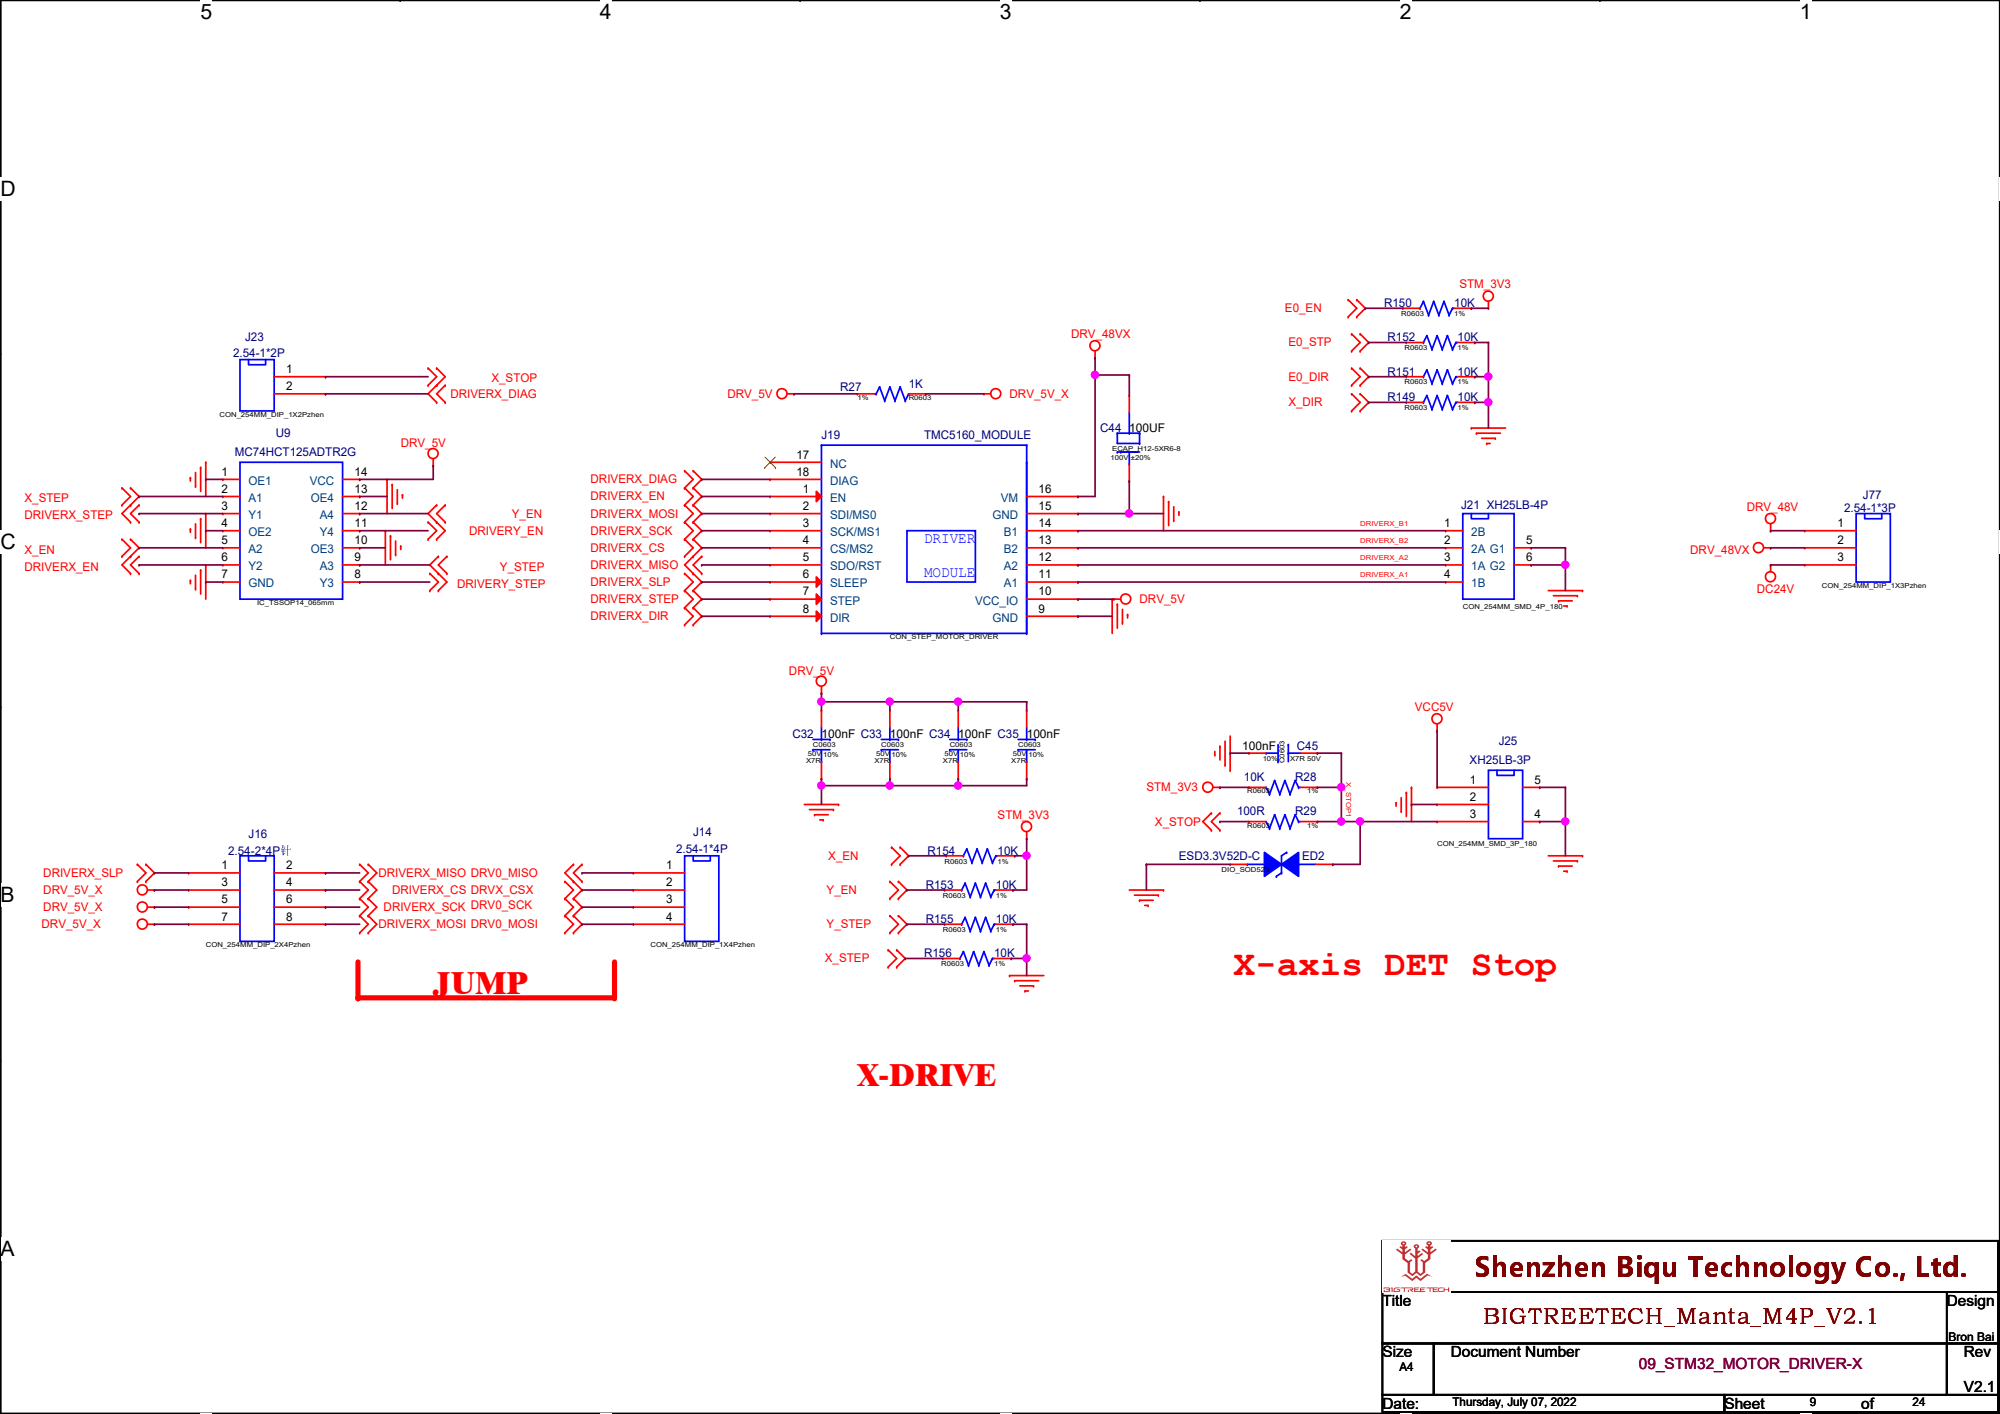
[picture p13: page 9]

Shenzhen Biqu Technology Co., Ltd.

D D

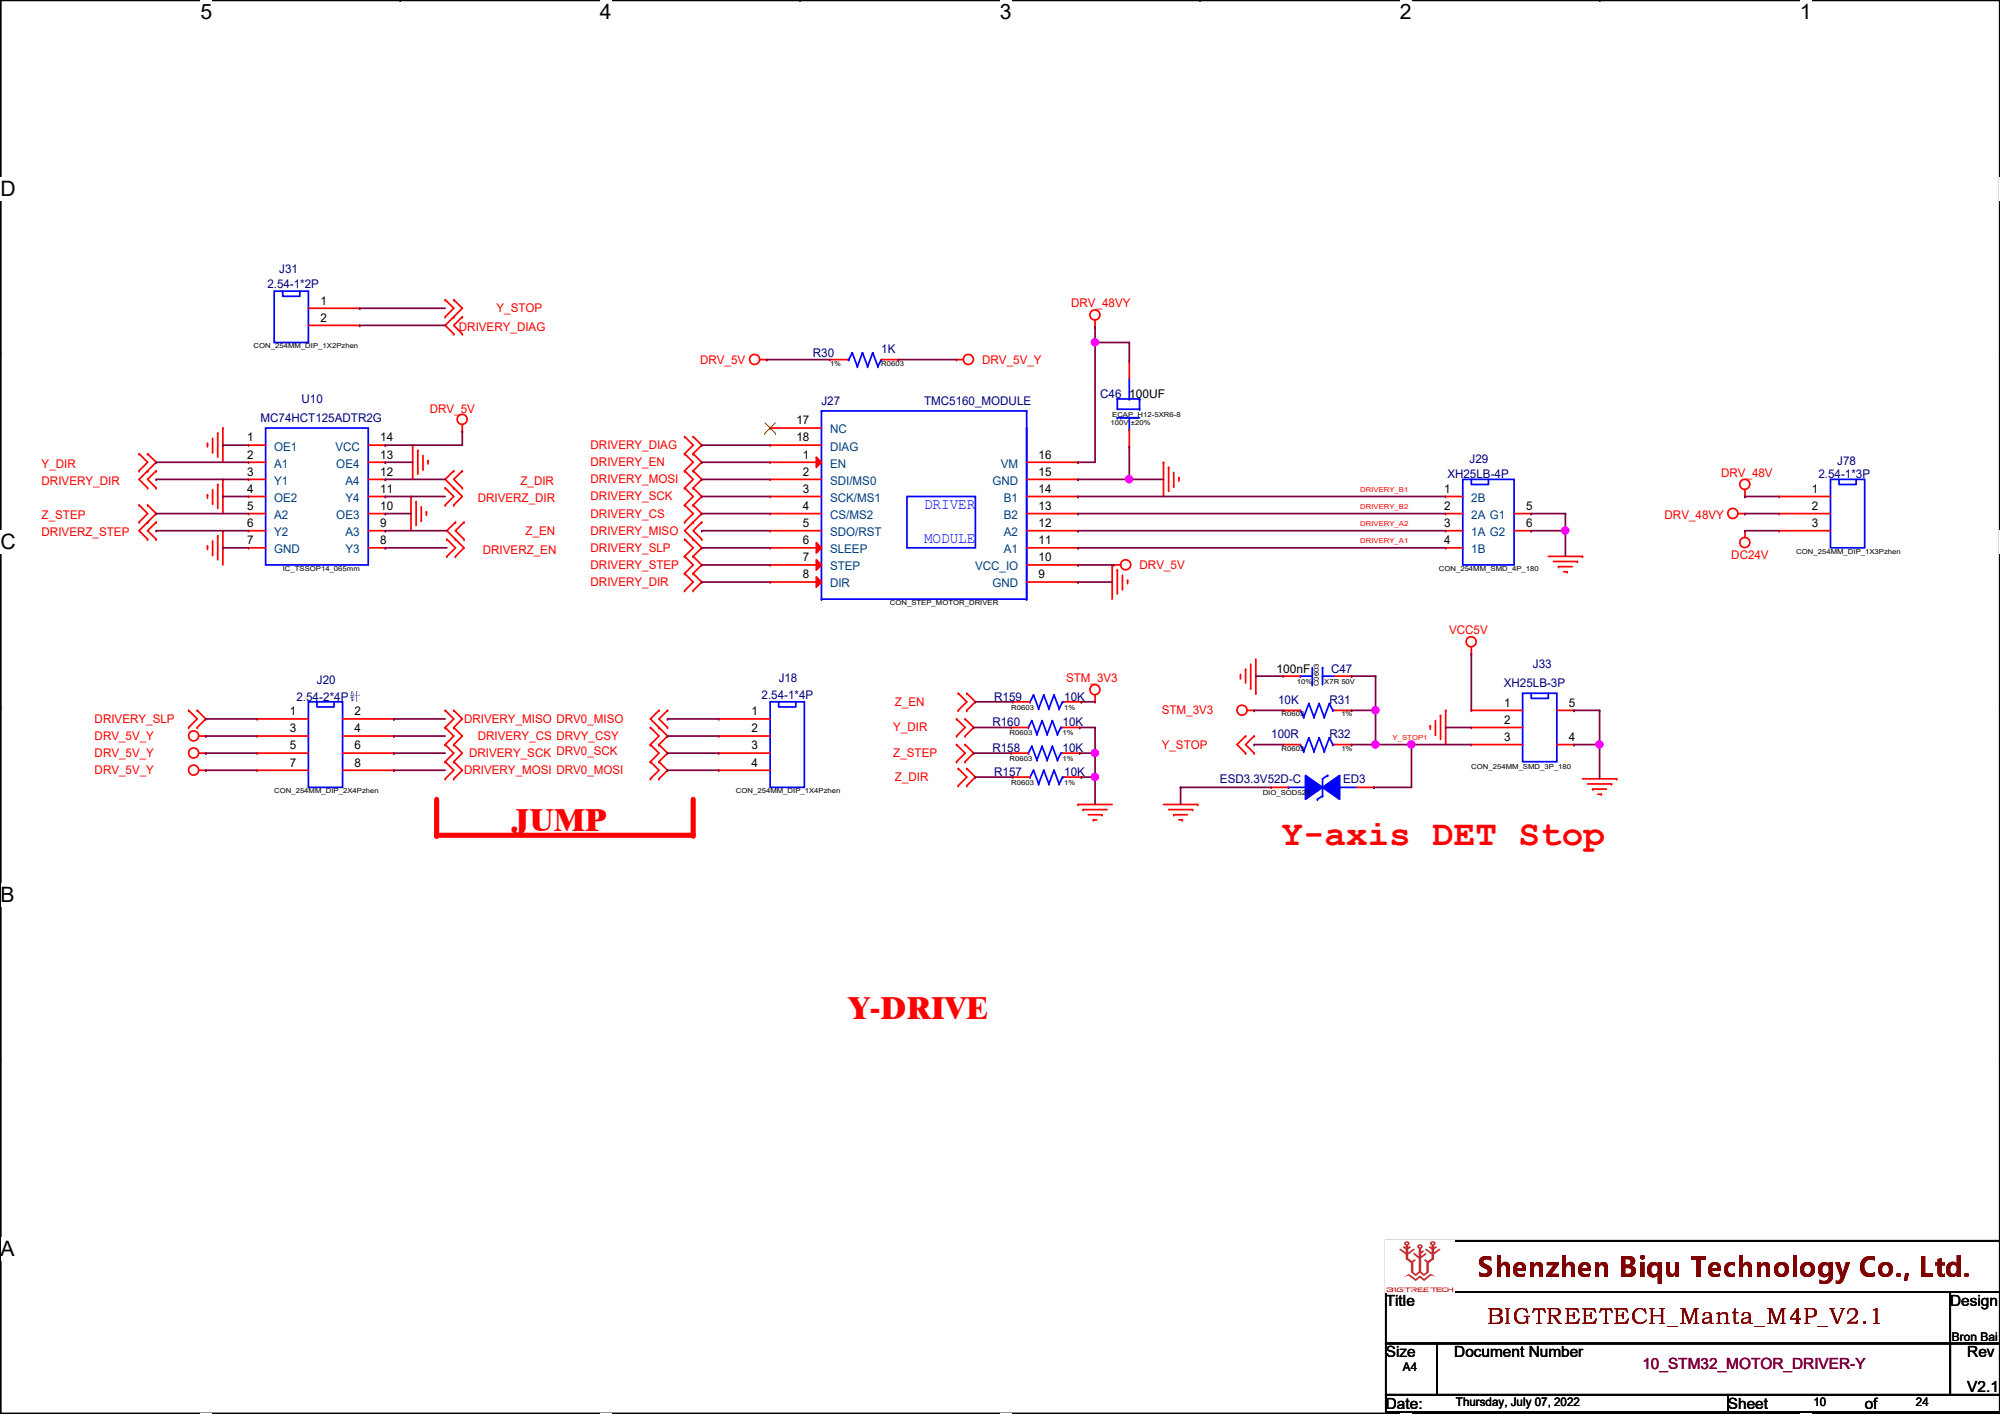
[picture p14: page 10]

Shenzhen Biqu Technology Co., Ltd.

D D

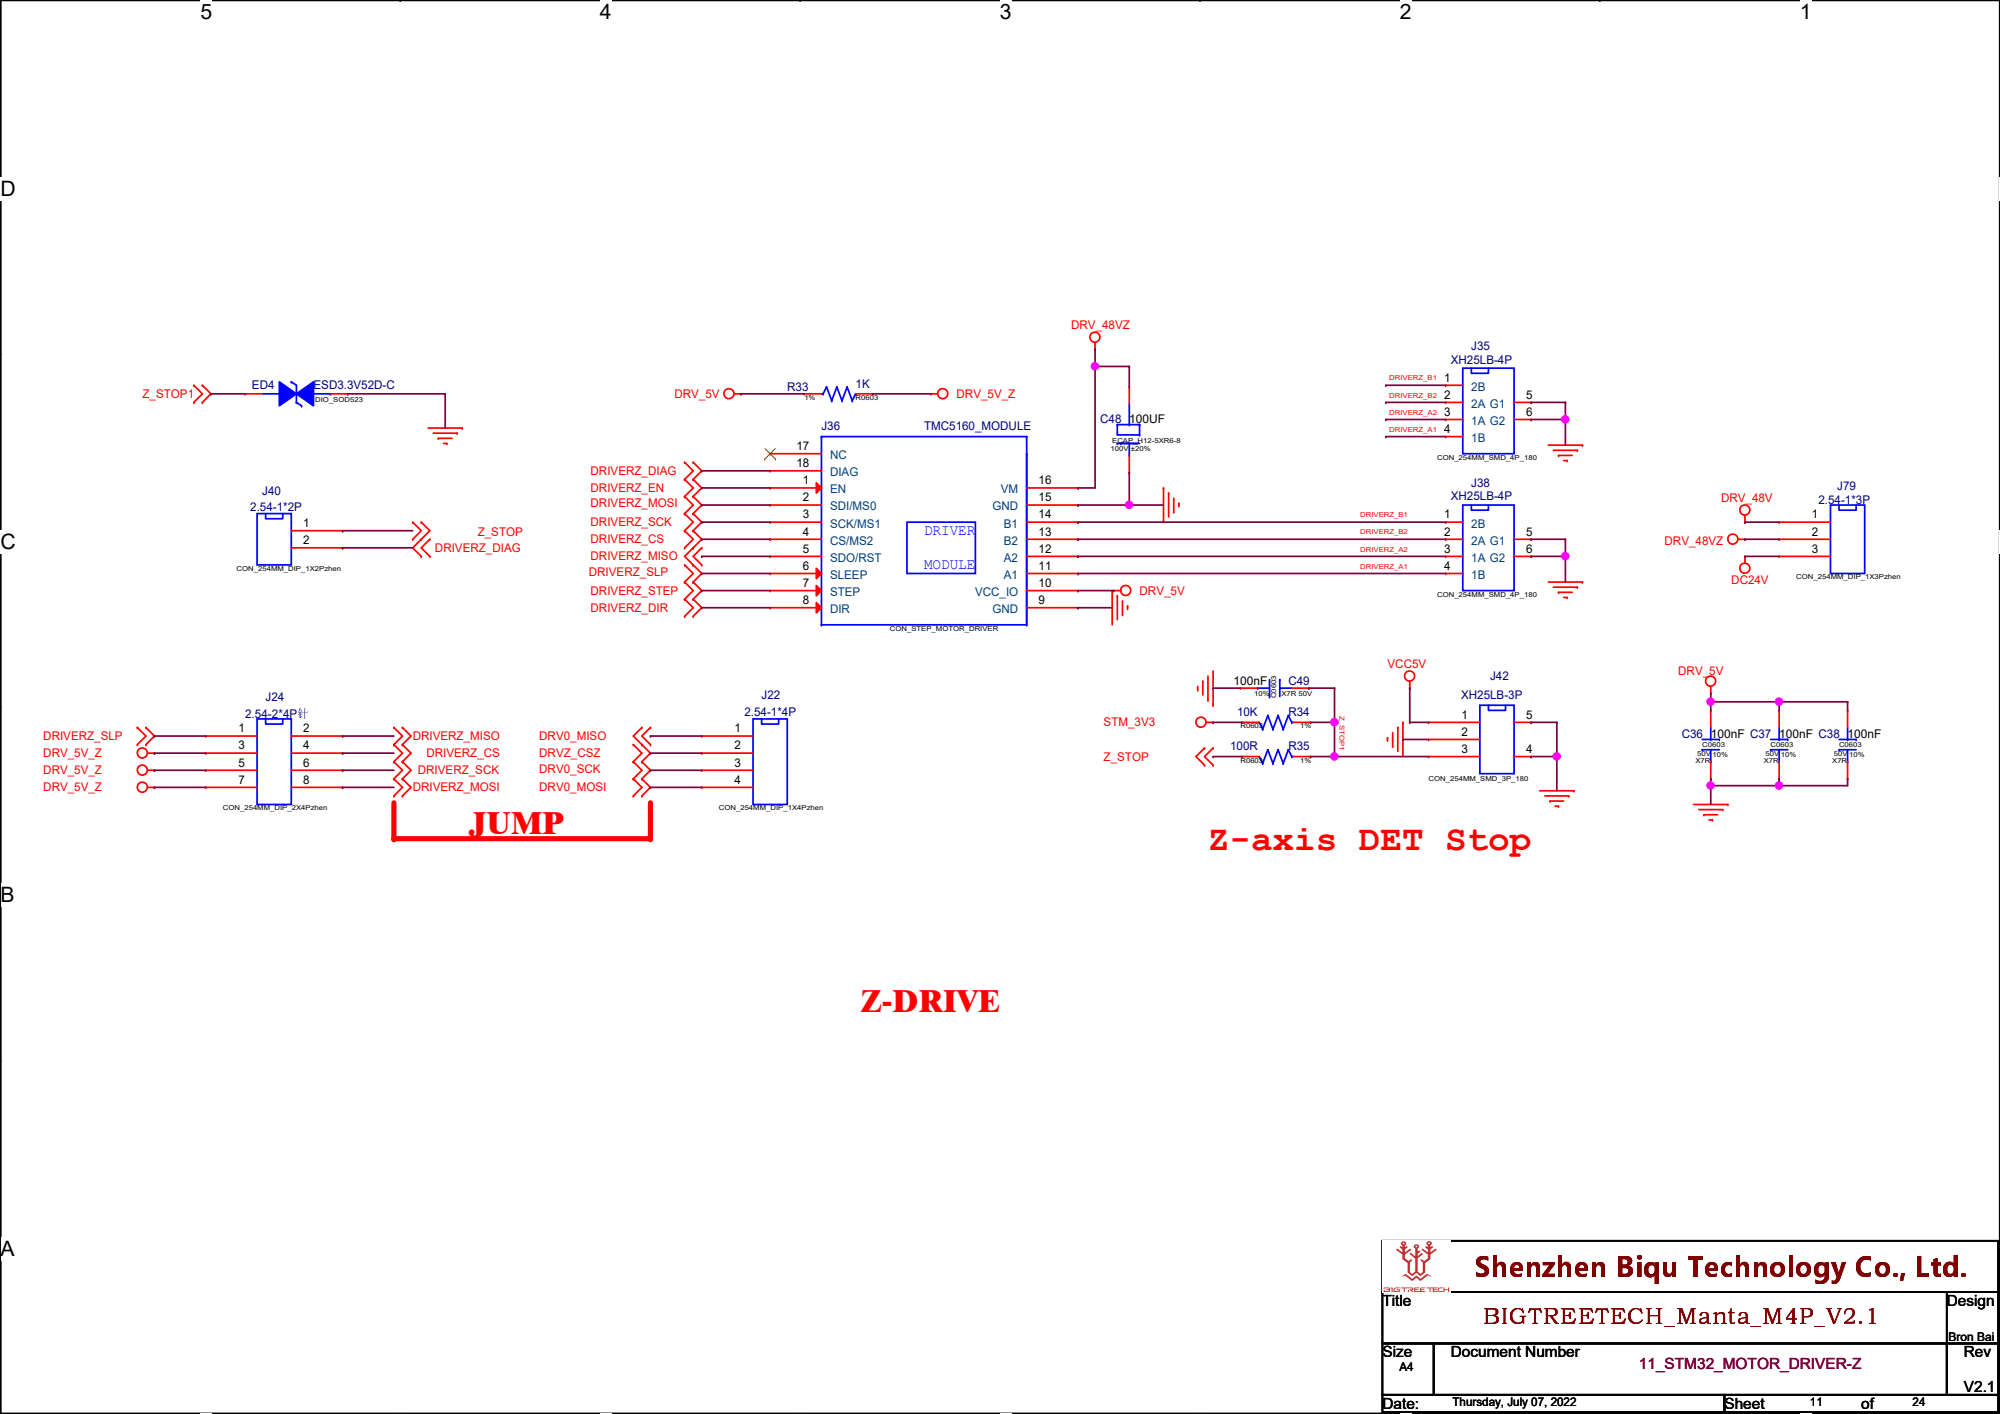
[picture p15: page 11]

Shenzhen Biqu Technology Co., Ltd.

D D

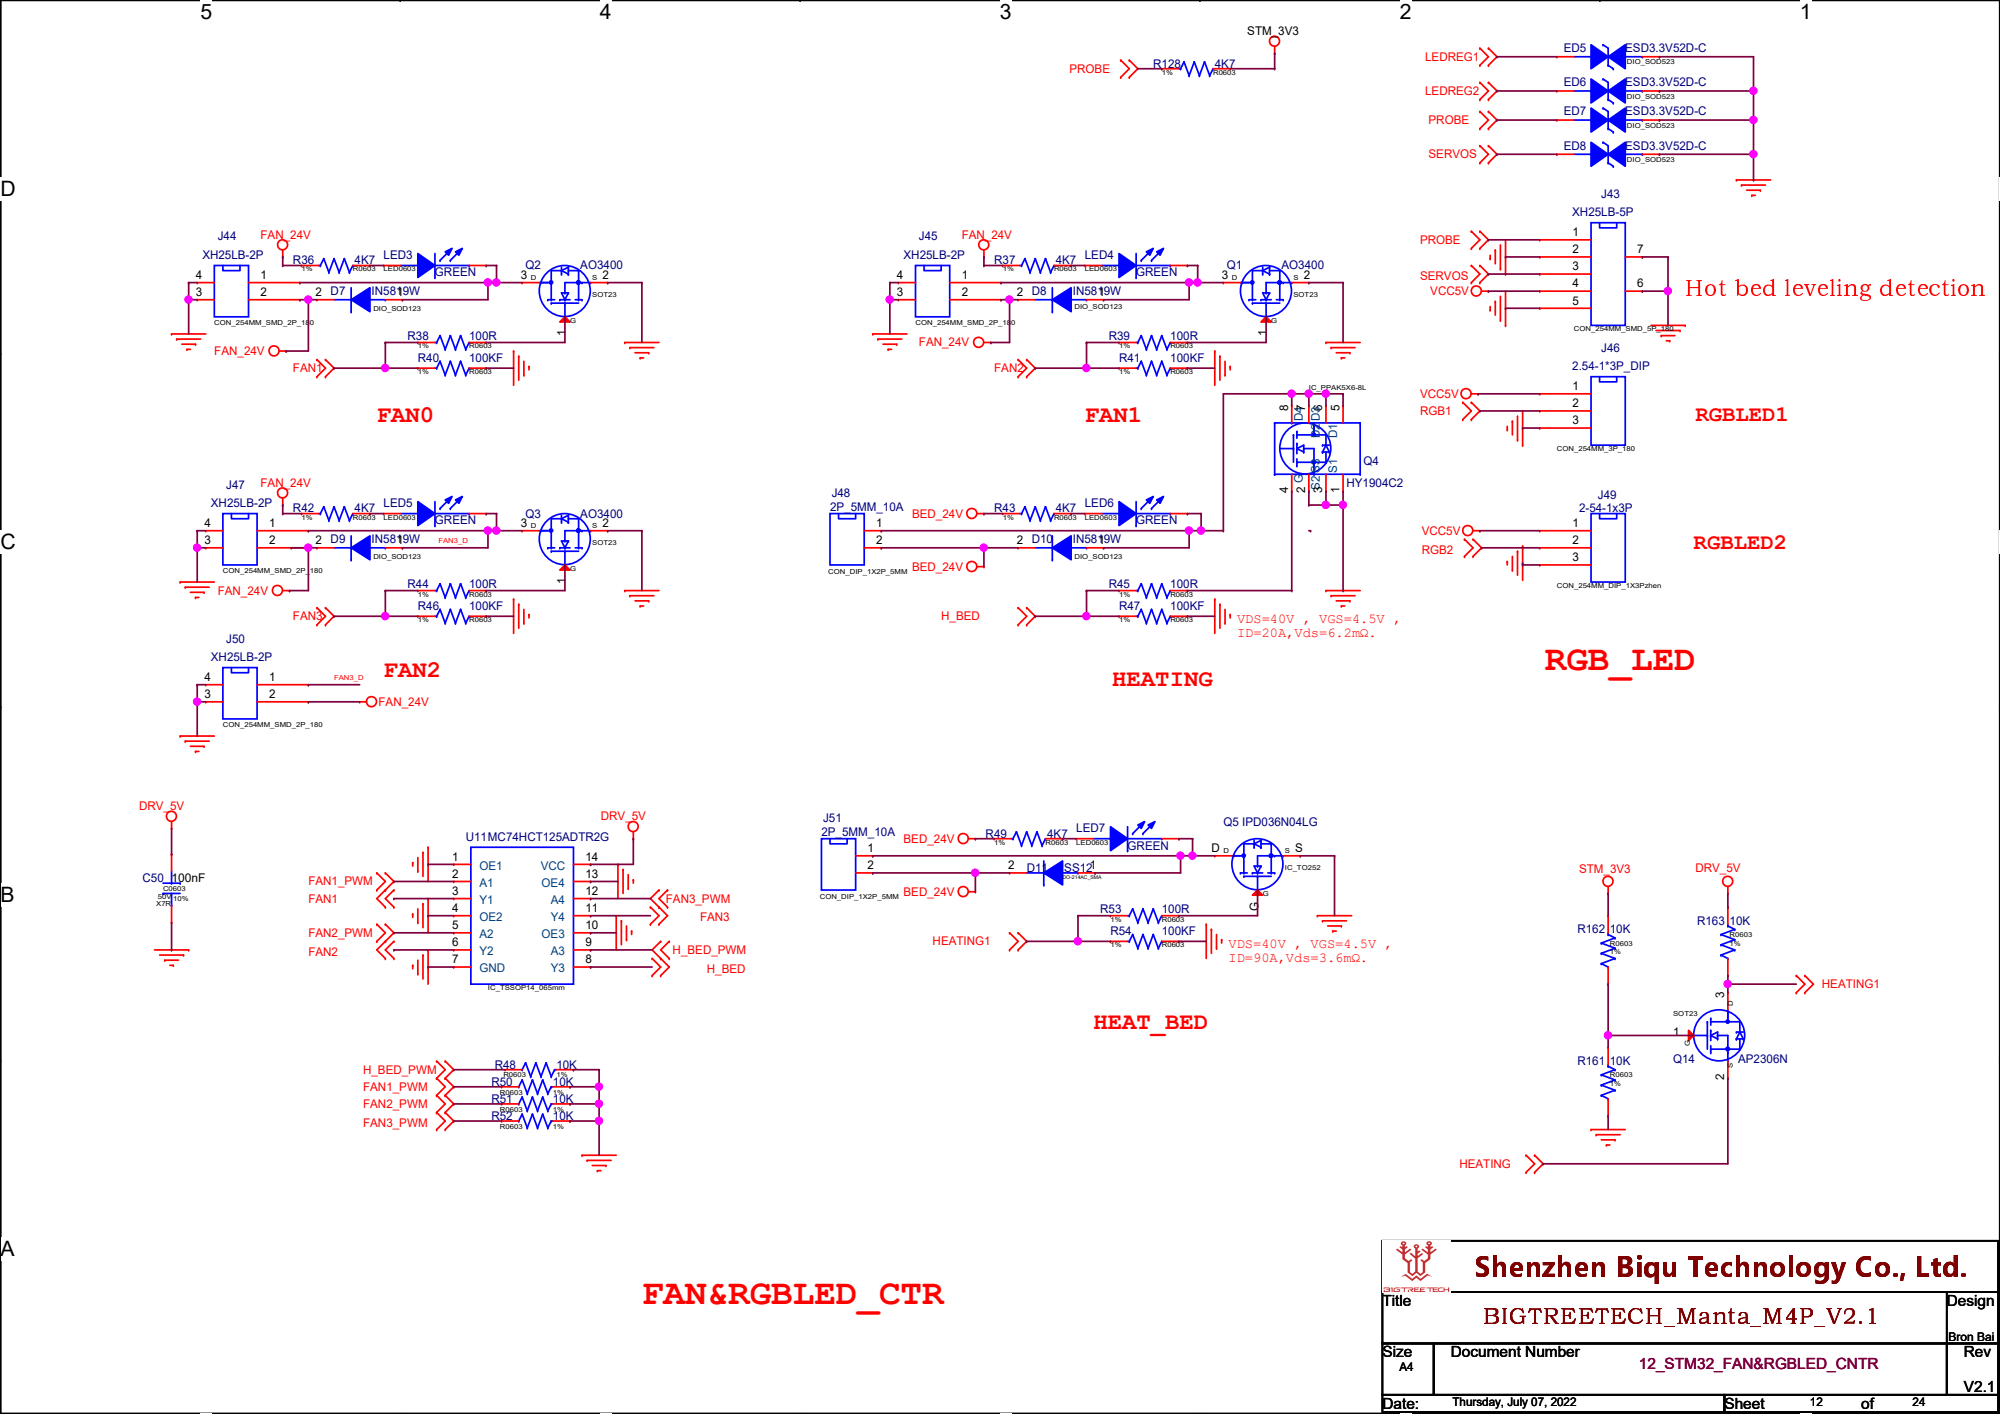
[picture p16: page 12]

Hot bed leveling detection

Shenzhen Biqu Technology Co., Ltd.

D D


Description: Onboard SD card, drive SPI, expand SPI share G0B1 SPI1 (PA4, PA5, PA6, PA7)

Shenzhen Biqu Technology Co., Ltd.

D D


Shenzhen Biqu Technology Co., Ltd.

D D


Expand SPI to share G0B1 SPI1

Shenzhen Biqu Technology Co., Ltd.

D D

## Gigabit


USB HOST power EN is the SD card power enable

CB1 Reserve IO,37 IO Ports.

CB1 power switch CB1 system reset

Shenzhen Biqu Technology Co., Ltd.

D D
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




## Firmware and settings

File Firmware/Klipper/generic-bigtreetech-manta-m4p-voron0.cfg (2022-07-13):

# This file contains common pin mappings for the BIGTREETECH Manta M4P
# To use this config, the firmware should be compiled for the
# STM32G0B1 with a "8KiB bootloader" and USB communication.

## Voron Design VORON 0.1 SKR Mini E3 V3 config

## *** THINGS TO CHANGE/CHECK: ***
## MCU path                                                                     [mcu] section
## Z and Extruder motor currents                                                [tmc2209 stepper_*] sections. Uncomment the stepper motor you have
## Full steps per rotation for Extruder                                         [extruder] section
## Thermistor types                                                             [extruder] and [heater_bed] sections - See https://www.klipper3d.org/Config_Reference.html#common-thermistors for common thermistor types
## Extruder motor currents                                                      [extruder] section
## PID tune                                                                     [extruder] and [heater_bed] sections
## Fine tune E steps                                                            [extruder] section
## For more info                                                                check https://docs.vorondesign.com/build/startup/#v0

[mcu]
#####################################################################
# Obtain definition by "ls -l /dev/serial/by-id/"
#####################################################################
serial: /dev/serial/by-id/usb-Klipper_stm32g0b1xx_REPLACE_WITH_YOUR_VALUE

[printer]
kinematics: corexy
max_velocity: 200
max_accel: 2000
max_z_velocity: 15
max_z_accel: 45
square_corner_velocity: 6.0

#####################################################################
#      X/Y Stepper Settings
#####################################################################

[stepper_x]
step_pin: PC6
## Refer to https://docs.vorondesign.com/build/startup/#v0
dir_pin: PA14                                                       # Check motor direction in link above. If inverted, add a ! before PB12
enable_pin: !PC7
rotation_distance: 40
microsteps: 32
full_steps_per_rotation: 200                                        # Set to 400 for 0.9° degree stepper motor, 200 is for 1.8° stepper motors
endstop_pin: ^PC0 
position_endstop: 120
position_max: 120
homing_speed: 50                                                    # Can be increased after initial setup, Max 100
homing_retract_dist: 5
homing_positive_dir: true

[tmc2209 stepper_x]
uart_pin: PB12
interpolate: False
run_current: 0.5
sense_resistor: 0.110
stealthchop_threshold: 0                                            # Set to 999999 to turn stealthchop on, and 0 to use spreadcycle

[stepper_y]
step_pin: PB10
## Refer to https://docs.vorondesign.com/build/startup/#v0
dir_pin: PB2                                                        # Check motor direction in link above. If inverted, add a ! before PB2
enable_pin: !PB11
rotation_distance: 40
microsteps: 32
full_steps_per_rotation: 200                                        # Set to 400 for 0.9° degree stepper motor, 200 is for 1.8° stepper motors
endstop_pin: ^PC1
position_endstop: 120
position_max: 120
homing_speed: 50                                                    # Can be increased after initial setup, Max 100
homing_retract_dist: 5
homing_positive_dir: true

[tmc2209 stepper_y]
uart_pin: PC10
interpolate: False
run_current: 0.5
sense_resistor: 0.110
stealthchop_threshold: 0                                            # Set to 999999 to turn stealthchop on, and 0 to use spreadcycle

#####################################################################
#   Z Stepper Settings
#####################################################################

[stepper_z]
step_pin: PB0
dir_pin: !PC5                                                       # Remove the ! before PC5 if motor direction is inverted.
enable_pin: !PB1
rotation_distance: 8                                                # For T8x8 integrated lead screw
microsteps: 32
endstop_pin: ^PC2
position_endstop: -0.10
position_max: 120
position_min: -1.5
homing_speed: 10
second_homing_speed: 3.0
homing_retract_dist: 3.0

[tmc2209 stepper_z]
uart_pin: PC9
interpolate: False
## For OMC (StepperOnline) 17LS13-0404E-200G 0.4A 
#run_current: 0.2
## For LDO-42STH25-1004CL200E 1.0A
#run_current: 0.37
sense_resistor: 0.110
stealthchop_threshold: 0                                            # Set to 999999 to turn stealthchop on, and 0 to use spreadcycle

#####################################################################
#   Extruder
#####################################################################

[extruder]
step_pin: PB3
dir_pin: PB4                                                        # Add ! if moving opposite direction
enable_pin: !PD5
#full_steps_per_rotation: 200                                       # Set to 200 for LDO 1.8° stepper motor, and set to 400 for OMC(StepperOnline) 0.9° stepper motor
rotation_distance: 22.23                                            # See calibrating rotation_distance on extruders doc
gear_ratio: 50:10                                                   # For Mini Afterburner
microsteps: 32
nozzle_diameter: 0.400
filament_diameter: 1.750
heater_pin: PC8
## Check what thermistor type you have. See https://www.klipper3d.org/Config_Reference.html#common-thermistors for common thermistor types.
## Use "Generic 3950" for NTC 100k 3950 thermistors
#sensor_type:
sensor_pin: PA0
control: pid                                                        # Do PID calibration after initial checks
pid_Kp: 28.182
pid_Ki: 1.978
pid_Kd: 100.397
min_temp: 0
max_temp: 270
min_extrude_temp: 170
max_extrude_only_distance: 150
max_extrude_cross_section: 0.8
pressure_advance: 0.0                                               # See tuning pressure advance doc
pressure_advance_smooth_time: 0.040

[tmc2209 extruder]
uart_pin: PA13
interpolate: False
## For OMC (StepperOnline) 14HR07-1004VRN 1A 0.9°
#run_current: 0.5   # for OMC 14HR07-1004VRN rated at 1A
## For LDO LDO 36STH17-1004AHG 1A 1.8° 
#run_current: 0.3   # for LDO 36STH17-1004AHG
## For LDO LDO 36STH20-1004AHG 1A 1.8° 
#run_current: 0.6   # for LDO 36STH20-1004AHG
sense_resistor: 0.110
stealthchop_threshold: 0                                            # Set to 0 for spreadcycle, avoid using stealthchop on extruder

#####################################################################
#   Bed Heater
#####################################################################

[heater_bed]
heater_pin: PD8
## Check what thermistor type you have. See https://www.klipper3d.org/Config_Reference.html#common-thermistors for common thermistor types.
## Use "Generic 3950" for Keenovo heaters
#sensor_type:
sensor_pin: PC4
smooth_time: 3.0
#max_power: 0.6                                                     # Only needed for 100w pads
min_temp: 0
max_temp: 120
control: pid                                                        # Do PID calibration after initial checks
pid_kp: 68.453
pid_ki: 2.749
pid_kd: 426.122

#####################################################################
#   Fan Control
#####################################################################

[heater_fan hotend_fan]
# FAN1
pin: PD3
max_power: 1.0
kick_start_time: 0.5
heater: extruder
heater_temp: 50.0
#fan_speed: 1.0                                                     # You can't PWM the delta fan unless using blue wire

[fan]
# FAN0
pin: PD2
max_power: 1.0
kick_start_time: 0.5                                                # Depending on your fan, you may need to increase this value if your fan will not start
off_below: 0.13
cycle_time: 0.010

#[fan_generic fan2]
## FAN2
#pin: PD4
#max_power: 1.0
#kick_start_time: 0.5                                                # Depending on your fan, you may need to increase this value if your fan will not start
#off_below: 0.13
#cycle_time: 0.010

#####################################################################
#   Homing and Gantry Adjustment Routines
#####################################################################

[idle_timeout]
timeout: 1800

[safe_z_home]
home_xy_position: 120,120
speed: 50.0
z_hop: 5

## To be used with BED_SCREWS_ADJUST
[bed_screws]
screw1: 60,5
screw1_name: front screw
screw2: 5,115
screw2_name: back left
screw3: 115,115
screw3_name: back right

#####################################################################
#   Macros
#####################################################################

[gcode_macro PRINT_START]
#   Use PRINT_START for the slicer starting script - please customize for your slicer of choice
gcode:
    G28                            ; home all axes
    G1 Z20 F3000                   ; move nozzle away from bed
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

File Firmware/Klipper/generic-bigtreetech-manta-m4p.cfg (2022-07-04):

# This file contains common pin mappings for the BIGTREETECH Manta M4P
# To use this config, the firmware should be compiled for the
# STM32G0B1 with a "8KiB bootloader" and USB communication.

# See docs/Config_Reference.md for a description of parameters.

[stepper_x]
step_pin: PC6
dir_pin: PA14
enable_pin: !PC7
microsteps: 16
rotation_distance: 40
endstop_pin: ^PC0
position_endstop: 0
position_max: 235
homing_speed: 50

[stepper_y]
step_pin: PB10
dir_pin: !PB2
enable_pin: !PB11
microsteps: 16
rotation_distance: 40
endstop_pin: ^PC1
position_endstop: 0
position_max: 235
homing_speed: 50

[stepper_z]
step_pin: PB0
dir_pin: !PC5
enable_pin: !PB1
microsteps: 16
rotation_distance: 8
endstop_pin: ^PC2
position_endstop: 0
position_max: 270
position_min: -5
homing_speed: 8
second_homing_speed: 3
homing_retract_dist: 3

[extruder]
step_pin: PB3
dir_pin: PB4
enable_pin: !PD5
microsteps: 16
rotation_distance: 22.9
nozzle_diameter: 0.400
filament_diameter: 1.750
heater_pin: PC8
sensor_type: Generic 3950
sensor_pin: PA0
control: pid
pid_Kp: 20.837
pid_Ki: 1.037
pid_Kd: 104.708
min_temp: 0
max_temp: 275

#[filament_switch_sensor extruder_filament_sensor]
#switch_pin: ^!PC15

[heater_bed]
heater_pin: PD8
sensor_type: Generic 3950
sensor_pin: PC4
control = pid
pid_kp = 62.901
pid_ki = 1.808
pid_kd = 547.241
min_temp: 0
max_temp: 120

[fan]
pin: PD2

#[heater_fan fan1]
#pin: PD3

#[heater_fan fan2]
#pin: PD4

#[bltouch]
#sensor_pin: PC14
#control_pin: PA1

#[adxl345]
#cs_pin: PD9
#spi_bus: spi1
#axes_map: z,y,-x

#[neopixel rgb1]
#pin: PD0

#[neopixel rgb2]
#pin: PD1

[mcu]
serial: /dev/serial/by-id/usb-Klipper_stm32g0b1xx_m4p-if00

[printer]
kinematics: cartesian
max_velocity: 180
max_accel: 3000
max_z_velocity: 5
max_z_accel: 100

########################################
# EXP1 / EXP2 (display) pins
########################################

[board_pins]
aliases:
    # EXP1 header
    EXP1_1=PD6,  EXP1_3=PB9,  EXP1_5=PA15, EXP1_7=PA9,   EXP1_9=<GND>,
    EXP1_2=PB8,  EXP1_4=PC3,  EXP1_6=PA10, EXP1_8=PB5,   EXP1_10=<5V>,
    # EXP2 header
    EXP2_1=PB14, EXP2_3=PC11, EXP2_5=PC12, EXP2_7=PC13,  EXP2_9=<GND>,
    EXP2_2=PB13, EXP2_4=PA8,  EXP2_6=PB15, EXP2_8=<RST>, EXP2_10=<NC>

# See the sample-lcd.cfg file for definitions of common LCD displays.

########################################
# TMC2209 configuration
########################################

#[tmc2209 stepper_x]
#uart_pin: PB12
#run_current: 0.800
#diag_pin:

#[tmc2209 stepper_y]
#uart_pin: PC10
#run_current: 0.800
#diag_pin:

#[tmc2209 stepper_z]
#uart_pin: PC9
#run_current: 0.800
#diag_pin:

#[tmc2209 extruder]
#uart_pin: PA13
#run_current: 0.600
#diag_pin:

########################################
# TMC5160 configuration
########################################

#[[tmc2130 stepper_x]
#cs_pin: PB12
#spi_bus: spi1
#diag1_pin: PG6
#run_current: 0.800
#stealthchop_threshold: 999999

#[tmc2130 stepper_y]
#cs_pin: PC10
#spi_bus: spi1
#diag1_pin: PG9
#run_current: 0.800
#stealthchop_threshold: 999999

#[tmc2130 stepper_z]
#cs_pin: PC9
#spi_bus: spi1
#diag1_pin: PG10
#run_current: 0.650
#stealthchop_threshold: 999999

#[tmc2130 extruder]
#cs_pin: PA13
#spi_bus: spi1
#diag1_pin: PC15
#run_current: 0.650
#stealthchop_threshold: 999999

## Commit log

2022-07-04 init release
    [generic-bigtreetech-manta-m4p.cfg]
2022-07-13 add m4p for voron0 config
    [generic-bigtreetech-manta-m4p-voron0.cfg]
2022-07-22 M4P_Voron0_Mounting bracket
    [DIN Clips.STL, M4P_Voron0_Mounting bracket.STEP, M4P_Voron0_Mounting bracket.STL]
2025-03-27 manual: Raspberry Pi 2023-10-10 and later systems, the configuration path changes from '/boot/' to '/boot/firmware'
